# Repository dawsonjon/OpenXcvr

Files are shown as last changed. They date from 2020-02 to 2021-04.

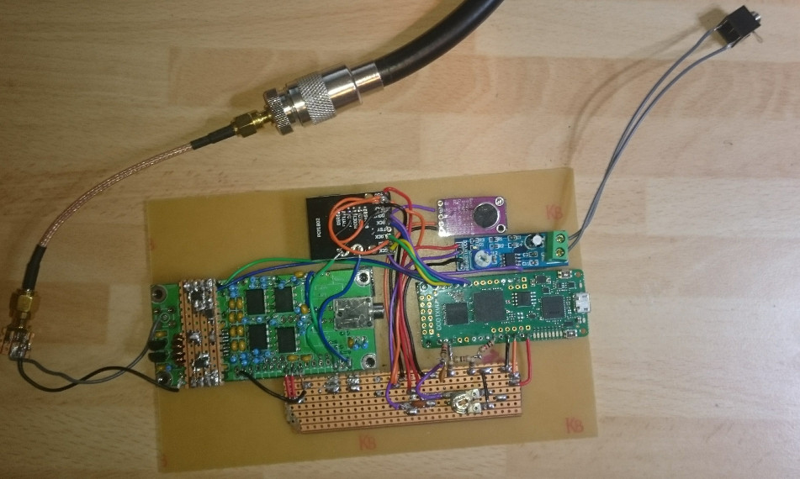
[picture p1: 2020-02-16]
images/prototype.jpg

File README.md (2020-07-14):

# Open XCVR

A cheap open-source Ham radio transceiver based on the [MAX1000 FPGA module](https://shop.trenz-electronic.de/en/Products/Trenz-Electronic/MAX1000-Intel-MAX10/). 

Features
+ High performance Intel MAX10 FPGA based DSP
+ SDR receiver 0.5-30MHz continuous
+ SDR transmitter 80m-10m ham bands
+ efficient 5W (ish) switched-mode PA for extended battery operation
+ Supports AM, FM, SSB and CW modes
+ audio output via 3.5mm headphone jack with integrated amplifier and provision for internal speaker
+ audio input via 3.5mm microphone jack with integrated pre-amplifier and provision for internal mic
+ support for straight and iambic telagraph keys with integrated electronic keyer
+ 500 general purpose memories
+ external 12v power via 2.5mm barrel jack provision for internal battery, integrated battery monitor
+ integrated Power/SWR meter
+ provision for GPS frequency calibration

The [wiki](https://github.com/dawsonjon/OpenXcvr/wiki) contains a detailed description of the hardware and firmware design

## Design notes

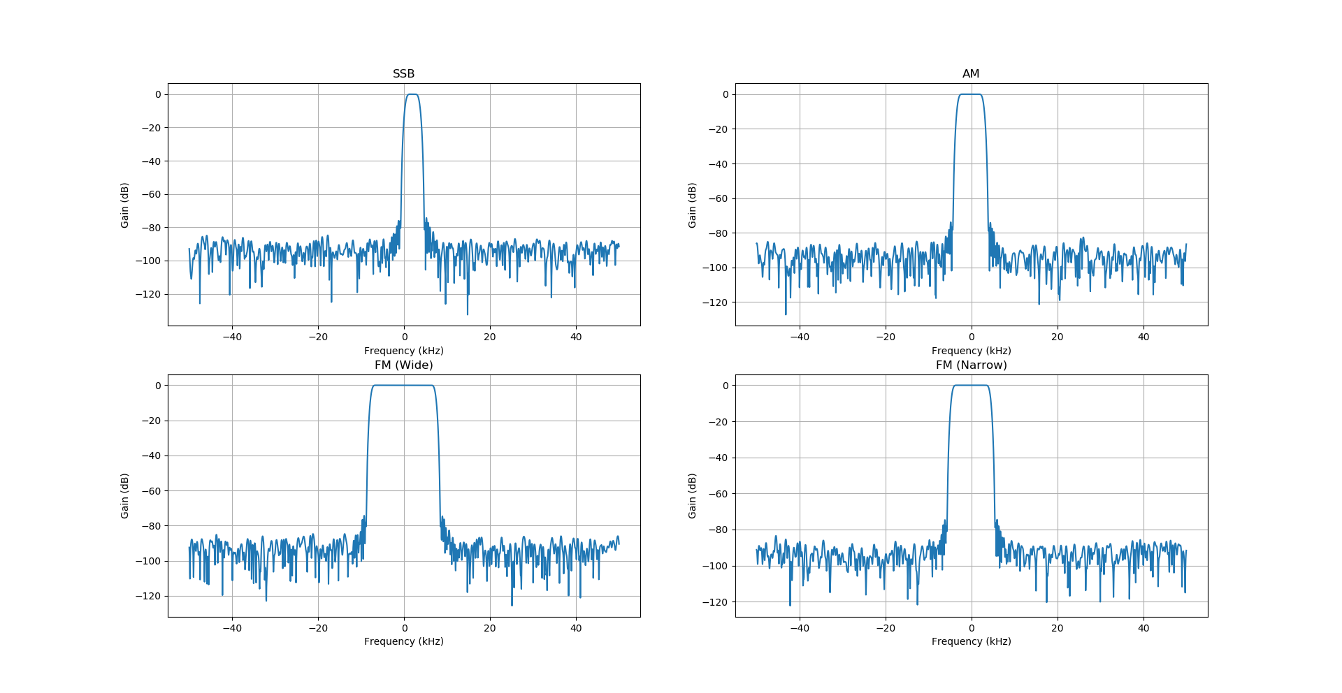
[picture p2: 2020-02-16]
images/digital_filter_response.png

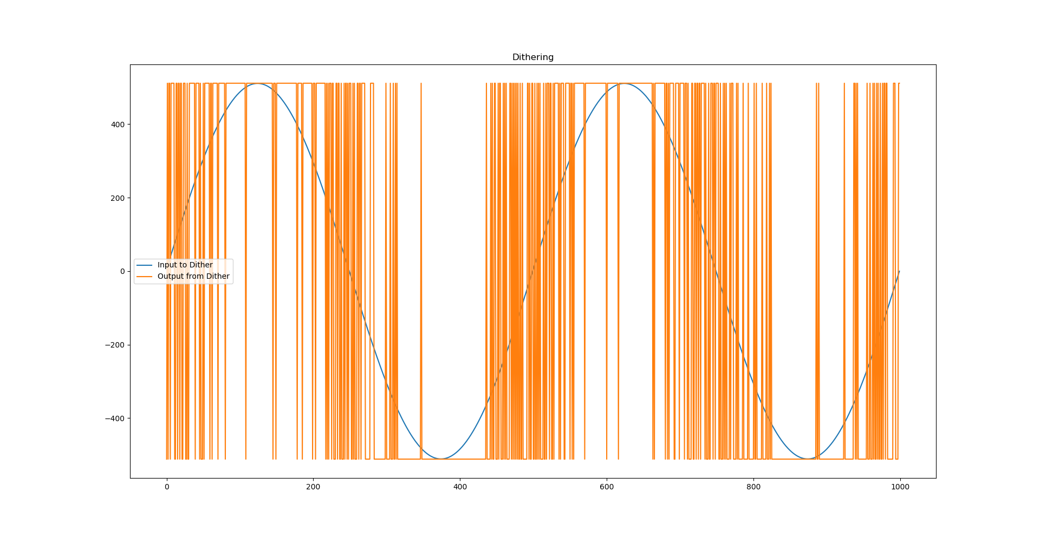
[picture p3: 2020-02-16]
images/dithering.png

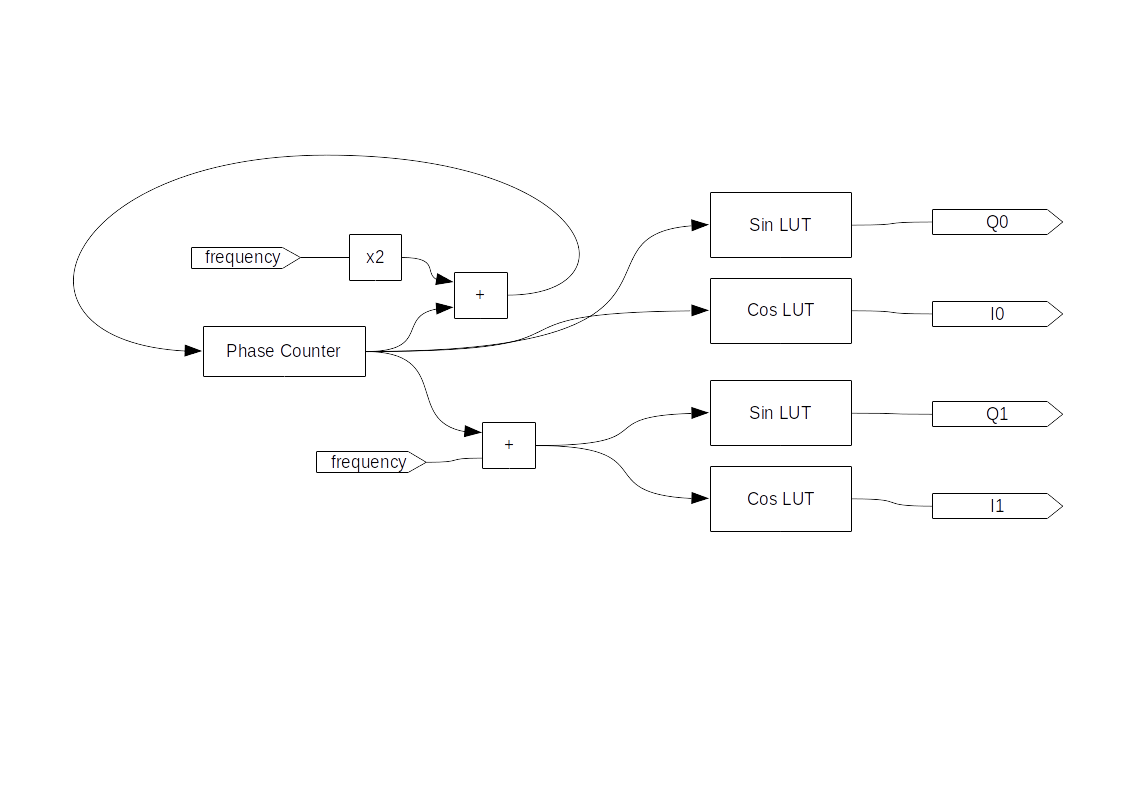
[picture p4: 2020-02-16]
images/NCO.png

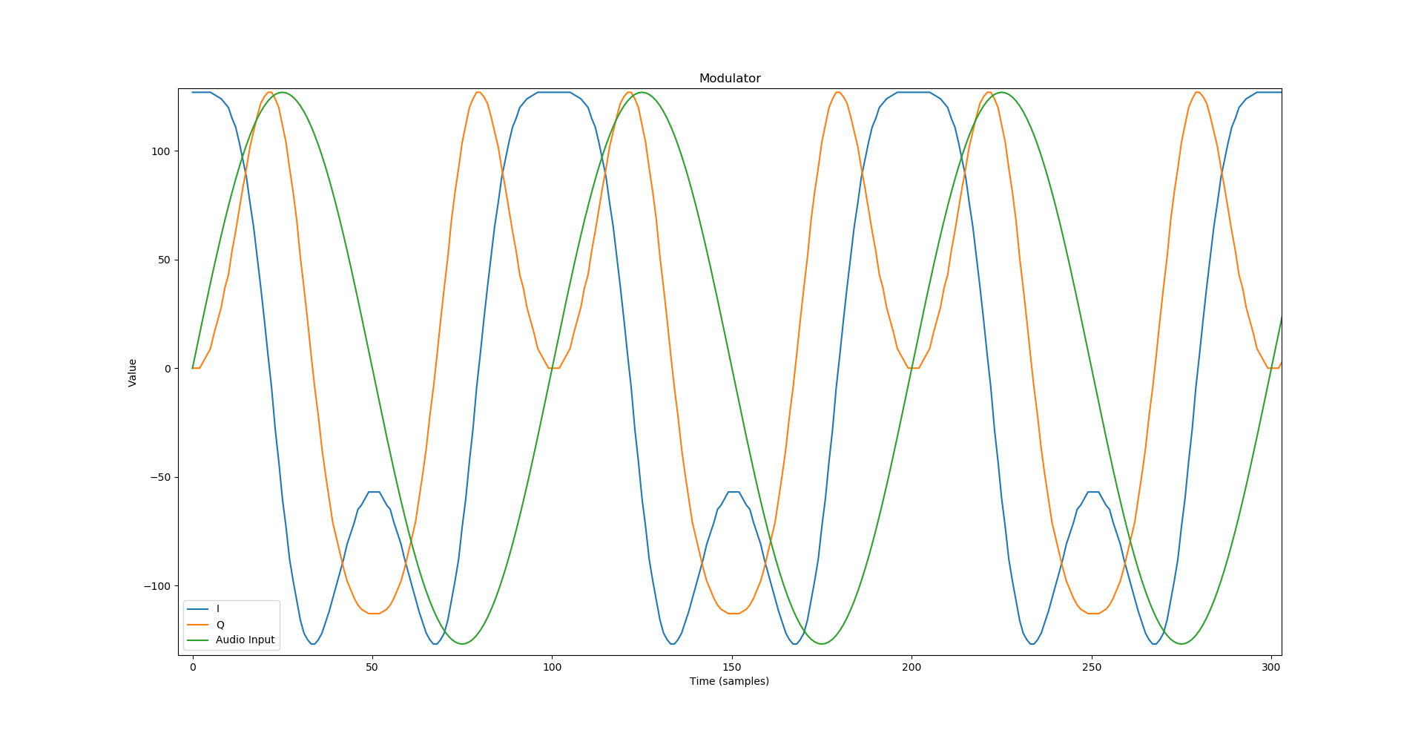
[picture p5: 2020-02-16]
images/modulator_fm.png

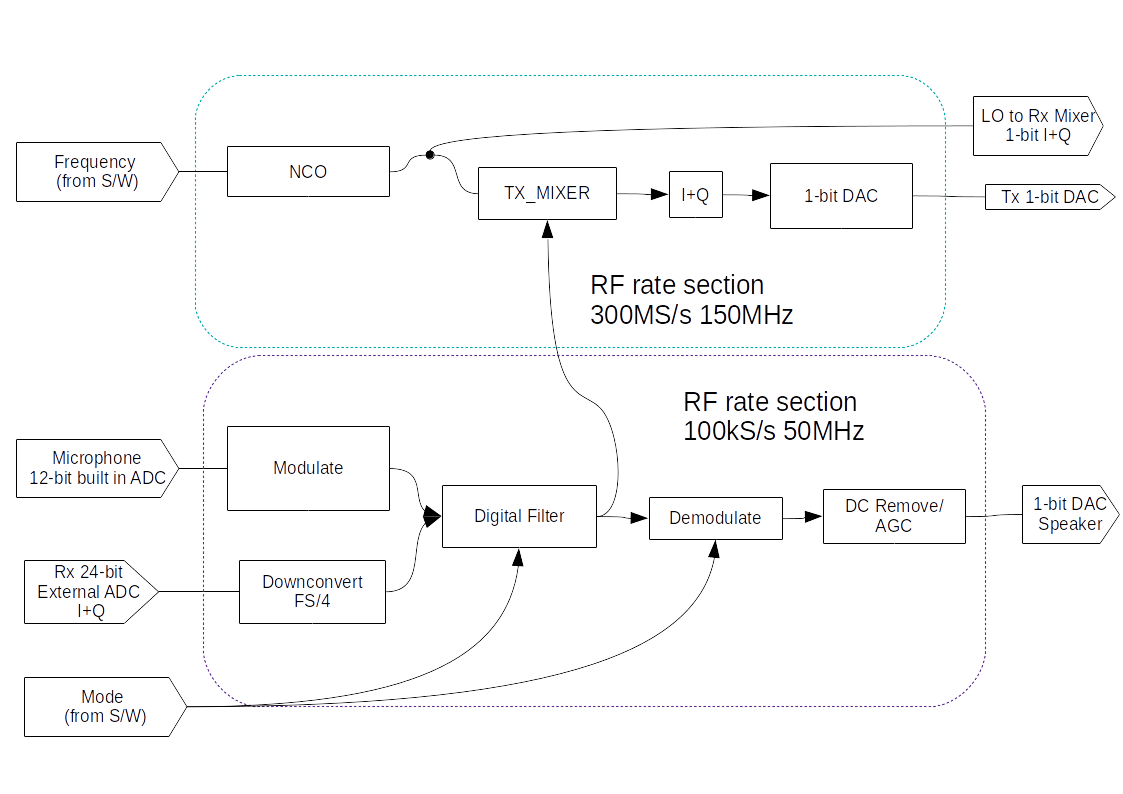
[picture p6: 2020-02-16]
images/firmware_top.png

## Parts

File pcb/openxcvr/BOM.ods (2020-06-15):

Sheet: Radio Board
Reference | Quantity | Value | Footprint | Datasheet | Total Cost GBP | Unit Cost GBP
C1 C2 C5 C6 | 4 | 10u | Capacitor_Tantalum_SMD:CP_EIA-3216-18_Kemet-A | ~ | 0.732 | 0.183 | https://uk.rs-online.com/web/p/tantalum-capacitors/5382278/
C21 C22 | 2 | 22n | Capacitor_SMD:C_0805_2012Metric | ~ | 0.258 | 0.129 | https://uk.rs-online.com/web/p/mlccs-multilayer-ceramic-capacitors/1795837/
C23 C24 C41 | 3 | 1n | Capacitor_SMD:C_0805_2012Metric | ~ | 0.3 | 0.1 | https://www.digikey.co.uk/product-detail/en/kemet/C0805C102J5GACTU/399-1136-1-ND/411411
C25 C26 | 2 | 1u | Capacitor_SMD:C_0805_2012Metric | ~ | 0.144 | 0.072 | https://uk.rs-online.com/web/p/mlccs-multilayer-ceramic-capacitors/1358614/
C3 C4 C7 C8 C10 C11 C12 C13 C14 C15 C17 C18 C19 C20 C51 C27 C28 C29 C30 C31 C32 C33 C46 C47 C48 C49 C16 | 27 | 100n | Capacitor_SMD:C_0805_2012Metric | ~ | 0.54 | 0.02 | https://uk.rs-online.com/web/p/mlccs-multilayer-ceramic-capacitors/1349144/
C34 C40 C42 | 3 | 390p | Capacitor_SMD:C_0805_2012Metric | ~ | 0.33 | 0.11 | https://www.digikey.co.uk/product-detail/en/kemet/C0805C391J5GACTU/399-1132-1-ND/411407
C35 C43 | 2 | 820p | Capacitor_SMD:C_0805_2012Metric | ~ | 0.032 | 0.016 | https://www.digikey.co.uk/product-detail/en/kemet/C0805C821J5GACTU/399-8119-1-ND/3471842
C36 C44 | 2 | 1n6 | Capacitor_SMD:C_0805_2012Metric | ~ | 0.84 | 0.42 | https://www.digikey.co.uk/product-detail/en/kemet/C0805C162J5GAC7800/399-15458-1-ND/7386856
C37 C45 | 2 | 3n | Capacitor_SMD:C_0805_2012Metric | ~ | 1.14 | 0.57 | https://www.digikey.co.uk/product-detail/en/kemet/C0805C302J5GAC7800/399-15039-1-ND/7382588
C38 | 1 | 100p | Capacitor_SMD:C_0805_2012Metric | ~ | 0.08 | 0.08 | https://www.digikey.co.uk/product-detail/en/kemet/C0805C101J5GACTU/399-1122-1-ND/411397
C39 | 1 | 200p | Capacitor_SMD:C_0805_2012Metric | ~ | 0.25 | 0.25 | https://www.digikey.co.uk/product-detail/en/kemet/C0805C201J5GAC7800/399-15466-1-ND/7386864
C50 | 1 | 47p | Capacitor_SMD:C_0805_2012Metric | ~ | 0.044 | 0.044 | https://uk.rs-online.com/web/p/mlccs-multilayer-ceramic-capacitors/2644270/
C9 | 1 | 47n | Capacitor_SMD:C_0805_2012Metric | ~ | 0.094 | 0.094 | https://uk.rs-online.com/web/p/mlccs-multilayer-ceramic-capacitors/0391303/
DS1 | 1 | WC1602A | Display:WC1602A | http://www.wincomlcd.com/pdf/WC1602A-SFYLYHTC06.pdf | 4.96 | 4.96 | https://www.rapidonline.com/winstar-wh1602b-yyh-jt-16x2-lcd-display-yellow-green-led-backlight-57-2226
FB1 FB2 FB3 | 3 | Ferrite_Bead | Inductor_SMD:L_0805_2012Metric | ~ | 0.516 | 0.172 | https://uk.rs-online.com/web/p/ferrite-beads/1241838/
H1 H2 H3 H4 | 4 | MountingHole_Pad | MountingHole:MountingHole_3.2mm_M3_Pad | ~ | 0 | 0 | N/A
J1 | 1 | Microphone | openxcvr:jack3.5mm switched | ~ | 0.662 | 0.662 | https://uk.rs-online.com/web/p/jack-plugs/9131021/
J2 | 1 | Mic | Connector_PinHeader_2.54mm:PinHeader_1x02_P2.54mm_Vertical | ~ | 0 | 0 | N/A
J3 | 1 | Speaker | Connector_PinHeader_2.54mm:PinHeader_1x02_P2.54mm_Vertical | ~ | 0 | 0 | N/A
J4 | 1 | Headphone | openxcvr:jack3.5mm switched | ~ | 0.662 | 0.662 | https://uk.rs-online.com/web/p/jack-plugs/9131021/
J5 | 1 | Conn_02x08_Odd_Even | Connector_PinHeader_2.54mm:PinHeader_2x08_P2.54mm_Vertical | ~ | 0 | 0 | N/A
J6 | 1 | GPS_CONNECTOR | Connector_PinHeader_2.54mm:PinHeader_1x02_P2.54mm_Vertical | ~ | 0 | 0 | N/A
J7 | 1 | KEY | openxcvr:jack3.5mm switched | ~ | 0.662 | 0.662 | https://uk.rs-online.com/web/p/jack-plugs/9131021/
J8 | 1 | Conn_01x03_Male | Connector_PinHeader_2.54mm:PinHeader_1x03_P2.54mm_Vertical | ~ | 0 | 0 | N/A
L1 L9 | 2 | 100n | Inductor_SMD:L_TDK_NLV32_3.2x2.5mm | ~ | 0.42 | 0.21 | https://www.digikey.co.uk/product-detail/en/tdk-corporation/NLV32T-R10J-EF/445-16614-1-ND/4766615
L10 L2 | 2 | 220n | Inductor_SMD:L_TDK_NLV32_3.2x2.5mm | ~ | 0.42 | 0.21 | https://www.digikey.co.uk/product-detail/en/tdk-corporation/NLV32T-R22J-EF/445-16622-1-ND/4766619
L11 L3 L5 | 3 | 470n | Inductor_SMD:L_TDK_NLV32_3.2x2.5mm | ~ | 0.63 | 0.21 | https://www.digikey.co.uk/product-detail/en/tdk-corporation/NLV32T-R47J-EF/445-16630-1-ND/4766623
L12 L4 L6 | 3 | 1u | Inductor_SMD:L_TDK_NLV32_3.2x2.5mm | ~ | 0.63 | 0.21 | https://www.digikey.co.uk/product-detail/en/tdk-corporation/NLV32T-1R0J-EF/445-16564-1-ND/4766590
L7 | 1 | 2u2 | Inductor_SMD:L_TDK_NLV32_3.2x2.5mm | ~ | 0.21 | 0.21 | https://www.digikey.co.uk/product-detail/en/tdk-corporation/NLV32T-2R2J-EF/445-16580-1-ND/4766598
L8 | 1 | 3u3 | Inductor_SMD:L_TDK_NLV32_3.2x2.5mm | ~ | 0.21 | 0.21 | https://www.digikey.co.uk/product-detail/en/tdk-corporation/NLV32T-3R3J-EF/445-16592-1-ND/4766604
R1 R2 R3 R8 | 4 | 1K | Resistor_SMD:R_0805_2012Metric | ~ | 0.156 | 0.039 | https://uk.rs-online.com/web/p/surface-mount-fixed-resistors/2230427/
R10 | 1 | 1M | Resistor_SMD:R_0805_2012Metric | ~ | 0.02 | 0.02 | https://uk.rs-online.com/web/p/surface-mount-fixed-resistors/2230821/
R11 R12 R6 R7 | 4 | 100K | Resistor_SMD:R_0805_2012Metric | ~ | 0.096 | 0.024 | https://uk.rs-online.com/web/p/surface-mount-fixed-resistors/2230691/
R13 R14 | 2 | 82 | Resistor_SMD:R_0805_2012Metric | ~ | 0.05 | 0.025 | https://uk.rs-online.com/web/p/surface-mount-fixed-resistors/7409057/
R15 R16 R21 R22 R23 R24 R25 R26 R27 R28 | 10 | 100 | Resistor_SMD:R_0805_2012Metric | ~ | 0.4 | 0.04 | https://uk.rs-online.com/web/p/surface-mount-fixed-resistors/0432214/
R17 R18 R34 R35 R36 R37 R38 R39 R41 | 9 | 2K2 | Resistor_SMD:R_0805_2012Metric | ~ | 0.261 | 0.029 | https://uk.rs-online.com/web/p/surface-mount-fixed-resistors/2230477/
R4 R5 R19 R20 R29 R30 R31 R32 R33 R40 R42 | 11 | 10K | Resistor_SMD:R_0805_2012Metric | ~ | 0.11 | 0.01 | https://uk.rs-online.com/web/p/surface-mount-fixed-resistors/1251189/
R43 R44 | 2 | 0 | Resistor_SMD:R_0805_2012Metric | ~ | 0.02 | 0.01 | https://uk.rs-online.com/web/p/surface-mount-fixed-resistors/1251187/
R9 | 1 | 47k | Resistor_SMD:R_0805_2012Metric | ~ | 0.013 | 0.013 | https://uk.rs-online.com/web/p/surface-mount-fixed-resistors/8075819/
RV3 | 1 | 10K | Potentiometer_THT:Potentiometer_Piher_PT-6-V_Vertical | ~ | 0.42 | 0.42 | https://uk.rs-online.com/web/p/trimmer-resistors/7432350/
SW1 SW2 SW3 SW4 | 4 | SW_Push | Button_Switch_THT:SW_PUSH_6mm | ~ | 1 | 0.25 | https://uk.rs-online.com/web/p/tactile-switches/3786476/
SW5 | 1 | Rotary_Encoder_Switch | Rotary_Encoder:RotaryEncoder_Alps_EC12E-Switch_Vertical_H20mm | ~ | 1.09 | 1.09 | https://uk.rs-online.com/web/p/mechanical-rotary-encoders/7295817/
T1 | 1 | BN43-2402 | openxcvr:bn43-2402-transformer | https://datasheet.octopart.com/CX2074NL-Pulse-datasheet-123678.pdf | 0.56 | 0.56 | http://www.amidoncorp.com/bn-43-2402/
U1 | 1 | PCM1802 | openxcvr:SSOP-20_5.3x7.2mm_P0.65mm |  | 1.84 | 1.84 | https://uk.rs-online.com/web/p/products/4619131/
U2 | 1 | TPA711D | Package_SO:SOIC-8_3.9x4.9mm_P1.27mm | https://www.ti.com/lit/ds/symlink/tpa711.pdf?ts=1590773198998 | 0.16 | 0.16 | https://uk.rs-online.com/web/p/products/6606310/
U3 | 1 | MCP6002-xSN | Package_SO:SOIC-8_3.9x4.9mm_P1.27mm | http://ww1.microchip.com/downloads/en/DeviceDoc/21733j.pdf | 0.25 | 0.25 | https://uk.rs-online.com/web/p/op-amps/6283598/
U4 | 1 | LM4562 | Package_SO:SOIC-8_3.9x4.9mm_P1.27mm | http://www.ti.com/lit/ds/symlink/lm4562.pdf | 1.29 | 1.29 | https://uk.farnell.com/texas-instruments/lm4562ma-nopb/op-amp-audio-dual-hf-8-so-powerwise/dp/3004532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
U5 | 1 | FST3253 | Package_SO:SOIC-16_3.9x9.9mm_P1.27mm | http://www.ti.com/lit/gpn/sn74cbt3253 | 0.166 | 0.166 | https://uk.rs-online.com/web/p/products/8076086/
U6 U7 | 2 | 74CBT3251 | Package_SO:SOIC-16_3.9x9.9mm_P1.27mm | http://www.ti.com/lit/gpn/sn74LS251 | 1.18 | 0.59 | https://www.digikey.co.uk/product-detail/en/SN74CBT3251DR/296-49883-1-ND/9462753?so=64190438
U8 | 1 | MAX_1000 | openxcvr:max1000 |  | 18.68 | 18.68 | https://shop.trenz-electronic.de/en/TEI0001-03-08-C8-MAX1000-IoT-Maker-Board-8KLE-8-MByte-RAM
U9 | 1 | 24LC256 | Package_SO:SOIC-8_3.9x4.9mm_P1.27mm | http://ww1.microchip.com/downloads/en/devicedoc/21203m.pdf | 0.622 | 0.622 | https://uk.rs-online.com/web/p/eeprom/0454331/
 |  |  |  |  | 43.15

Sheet: Transmit Board
Reference | Quantity | Value | Footprint | Total Price GBP | Unit Price GBP
C1 C13 | 2 | 56p | Capacitor_SMD:C_0805_2012Metric | 0.74 | 0.37 | https://www.digikey.co.uk/product-detail/en/08052U560GAT2A/478-10479-1-ND/6797386?so=64190438
C10 C6 | 2 | 390p | Capacitor_SMD:C_0805_2012Metric | 0.22 | 0.11 | https://www.digikey.co.uk/product-detail/en/kemet/C0805C391J5GACTU/399-1132-1-ND/411407
C11 C7 | 2 | 680p | Capacitor_SMD:C_0805_2012Metric | 0.66 | 0.33 | https://www.digikey.co.uk/product-detail/en/C0805C621J2GAC7800/399-17640-1-ND/8572640?so=64190438
C12 C8 | 2 | 1.2n | Capacitor_SMD:C_0805_2012Metric | 0.52 | 0.26 | https://www.digikey.co.uk/product-detail/en/C0805C122J2GAC7800/399-17620-1-ND/8572620?so=64190438
C14 C2 | 2 | 180p | Capacitor_SMD:C_0805_2012Metric | 0.54 | 0.27 | https://www.digikey.co.uk/product-detail/en/08052A181JAT2A/478-10441-1-ND/6797354?so=64190438
C15 C3 | 2 | 270p | Capacitor_SMD:C_0805_2012Metric | 0.56 | 0.28 | https://www.digikey.co.uk/product-detail/en/GRM21A5C2D271JW01D/490-16817-1-ND/7595725?so=64190438
C16 C4 | 2 | 470p | Capacitor_SMD:C_0805_2012Metric | 0.54 | 0.27 | https://www.digikey.co.uk/product-detail/en/08052A471JAT2A/478-1276-1-ND/564308?so=64190438
C18 C19 | 2 | 10u | Capacitor_Tantalum_SMD:CP_EIA-3216-18_Kemet-A | 0.366 | 0.183 | https://uk.rs-online.com/web/p/tantalum-capacitors/5382278/
C21 C26 | 2 | 68n | Capacitor_SMD:C_0805_2012Metric | 0.044 | 0.022 | https://uk.rs-online.com/web/p/mlccs-multilayer-ceramic-capacitors/0147796/
C22 C23 C24 C27 C28 C17 C20 | 7 | 100n | Capacitor_SMD:C_0805_2012Metric | 0.56 | 0.08 | https://www.digikey.co.uk/product-detail/en/CL21B104KCFNNNE/1276-6840-1-ND/5961699?so=64190438
C25 | 1 | 220n | Capacitor_SMD:C_0805_2012Metric | 0.026 | 0.026 | https://uk.rs-online.com/web/p/mlccs-multilayer-ceramic-capacitors/0390996/
C5 C9 | 2 | 150p | Capacitor_SMD:C_0805_2012Metric | 0.54 | 0.27 | https://www.digikey.co.uk/product-detail/en/08052A151JAT2A/478-1273-1-ND/564305?so=64190438
D1 D2 D3 D4 | 4 | 1N4148W | Diode_SMD:D_SOD-123 | 0.276 | 0.069 | https://uk.rs-online.com/web/p/switching-diodes/7003671/
D5 D6 | 2 | 1N5711 | Diode_THT:D_DO-35_SOD27_P7.62mm_Horizontal | 0.64 | 0.32 | https://www.digikey.co.uk/product-detail/en/stmicroelectronics/1N5711/497-2499-1-ND/603881
D7 | 1 | D_Schottky | openxcvr:D_SOD-106 | 0.162 | 0.162 | https://uk.rs-online.com/web/p/products/7002665/
D8 | 1 | 51v | Diode_SMD:D_SOD-123 | 0.042 | 0.042 | https://uk.rs-online.com/web/p/products/7930933/
H1 H2 H3 H4 | 4 | MountingHole_Pad | MountingHole:MountingHole_3.2mm_M3_Pad | 0 | 0
J1 | 1 | Conn_Coaxial | Connector_Coaxial:BNC_Amphenol_B6252HB-NPP3G-50_Horizontal | 1.26 | 1.26 | https://uk.rs-online.com/web/p/coaxial-connectors/5121247/?searchHistory=%7B%22enabled%22%3Atrue%7D
J2 | 1 | RADIO BOARD CONNECTOR | Connector_PinHeader_2.54mm:PinHeader_2x08_P2.54mm_Vertical | 0 | 0
J3 | 1 | Power Jack | Connector_BarrelJack:BarrelJack_Horizontal | 1.07 | 1.07 | https://uk.rs-online.com/web/p/dc-power-connectors/8840944/?searchHistory=%7B%22enabled%22%3Atrue%7D
J4 | 1 | Battery Connector | Connector_PinHeader_2.54mm:PinHeader_1x02_P2.54mm_Vertical | 0 | 0
K1 K2 K3 K4 | 4 | G5V-2 | Relay_THT:Relay_DPDT_Omron_G5V-2 | 8.32 | 2.08 | https://uk.rs-online.com/web/p/non-latching-relays/1966276/
L1 L9 | 2 | 303n | openxcvr:FT37-INDUCTOR | 0.88 | 0.44 | https://www.amidoncorp.com/t37-6/
L10 L2 | 2 | 773n | openxcvr:FT37-INDUCTOR | 0.88 | 0.44 | https://www.amidoncorp.com/t37-6/
L11 L3 | 2 | 1.380u | openxcvr:FT37-INDUCTOR | 0.88 | 0.44 | https://www.amidoncorp.com/t37-6/
L12 L4 | 2 | 2.434u | openxcvr:FT37-INDUCTOR | 0.88 | 0.44 | https://www.amidoncorp.com/t37-2/
L13 L14 | 2 | 100u | openxcvr:L_SMT_INDUCTOR | 0.68 | 0.34 | https://uk.rs-online.com/web/p/wire-wound-surface-mount-inductors/7418997/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
L15 | 1 | L | openxcvr:FT50-43 INDUCTOR | 0.6 | 0.6 | http://www.amidoncorp.com/ft-50-43/
L5 | 1 | 382n | openxcvr:FT37-INDUCTOR | 0.44 | 0.44 | https://www.amidoncorp.com/t37-6/
L6 | 1 | 904n | openxcvr:FT37-INDUCTOR | 0.44 | 0.44 | https://www.amidoncorp.com/t37-6/
L7 | 1 | 1.698u | openxcvr:FT37-INDUCTOR | 0.44 | 0.44 | https://www.amidoncorp.com/t37-6/
L8 | 1 | 3.012u | openxcvr:FT37-INDUCTOR | 0.44 | 0.44 | https://www.amidoncorp.com/t37-2/
Q1 Q2 Q4 Q5 Q6 Q3 | 6 | BS170 | Package_TO_SOT_THT:TO-92_Inline | 1.182 | 0.197 | https://export.rsdelivers.com/product/on-semiconductor/bs170-d27z/on-semiconductor-bs170-d27z-digital-transistor-3/1868777
R1 R2 R3 | 3 | 10K | Resistor_SMD:R_0805_2012Metric | 0.03 | 0.01 | https://uk.rs-online.com/web/p/surface-mount-fixed-resistors/1251189/
R10 R11 R6 R9 | 4 | 100 | Resistor_SMD:R_0805_2012Metric | 0.16 | 0.04 | https://uk.rs-online.com/web/p/surface-mount-fixed-resistors/0432214/
R14 R15 | 2 | 10 | Resistor_SMD:R_0805_2012Metric | 0.02 | 0.01 | https://uk.rs-online.com/web/p/surface-mount-fixed-resistors/8123372/
R16 R17 R18 | 3 | 4k7 | Resistor_SMD:R_0805_2012Metric | 0.012 | 0.004 | https://uk.rs-online.com/web/p/surface-mount-fixed-resistors/0432416/
R19 R21 R12 R13 R4 R5 R7 | 7 | 10k | Resistor_SMD:R_0805_2012Metric | 0.07 | 0.01 | https://uk.rs-online.com/web/p/surface-mount-fixed-resistors/1251189/
R8 | 1 | 1K | Resistor_SMD:R_0805_2012Metric | 0.039 | 0.039 | https://uk.rs-online.com/web/p/surface-mount-fixed-resistors/2230427/
RV1 | 1 | 10k | Potentiometer_THT:Potentiometer_Piher_PT-6-V_Vertical | 0.42 | 0.42 | https://uk.rs-online.com/web/p/trimmer-resistors/7432350/
SW1 | 1 | POWER SWITCH | openxcvr:RS PCB Toggle Switch | 1.56 | 1.56 | https://uk.rs-online.com/web/p/products/7346971/
TR1 TR2 | 2 | FT50-43Transformer | openxcvr:FT50-43 Transformer | 1.2 | 0.6 | http://www.amidoncorp.com/ft-50-43/
U1 | 1 | LM7805CV_TO220 | Package_TO_SOT_THT:TO-220-3_Vertical | 0.42 | 0.42 | https://uk.rs-online.com/web/p/linear-voltage-regulators/7931346/?searchHistory=%7B%22enabled%22%3Atrue%7D
U2 U3 | 2 | to220heatsink | openxcvr:to220 heatsink | 0.312 | 0.156 | https://uk.rs-online.com/web/p/heatsinks/7124257/?searchHistory=%7B%22enabled%22%3Atrue%7D
U4 | 1 | MCP1406 | Package_SO:SOIC-8_3.9x4.9mm_P1.27mm | 0.668 | 0.668 | https://uk.rs-online.com/web/p/products/0403610/
U5 | 1 | DMC3056LSS | Package_SO:SOP-8_3.9x4.9mm_P1.27mm | 0.076 | 0.076 | https://uk.rs-online.com/web/p/products/8234037/
U6 | 1 | 74AC00 | Package_SO:SOIC-14_3.9x8.7mm_P1.27mm | 0.466 | 0.466 | https://uk.rs-online.com/web/p/logic-gates/7390145/?searchHistory=%7B%22enabled%22%3Atrue%7D
 |  |  |  | 30.281

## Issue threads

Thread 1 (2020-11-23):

Query on project progress

bob-g4bby, 2020-11-23:
Hi Jon,
Not an issue - wondered how you were getting on with using the transceiver on-air, whether you use it portable yet and have you got the pcbs working yet. I've been messing around with sdrs for as long as they've been round - see my QRZ page.
Best regards, Bob G4BBY

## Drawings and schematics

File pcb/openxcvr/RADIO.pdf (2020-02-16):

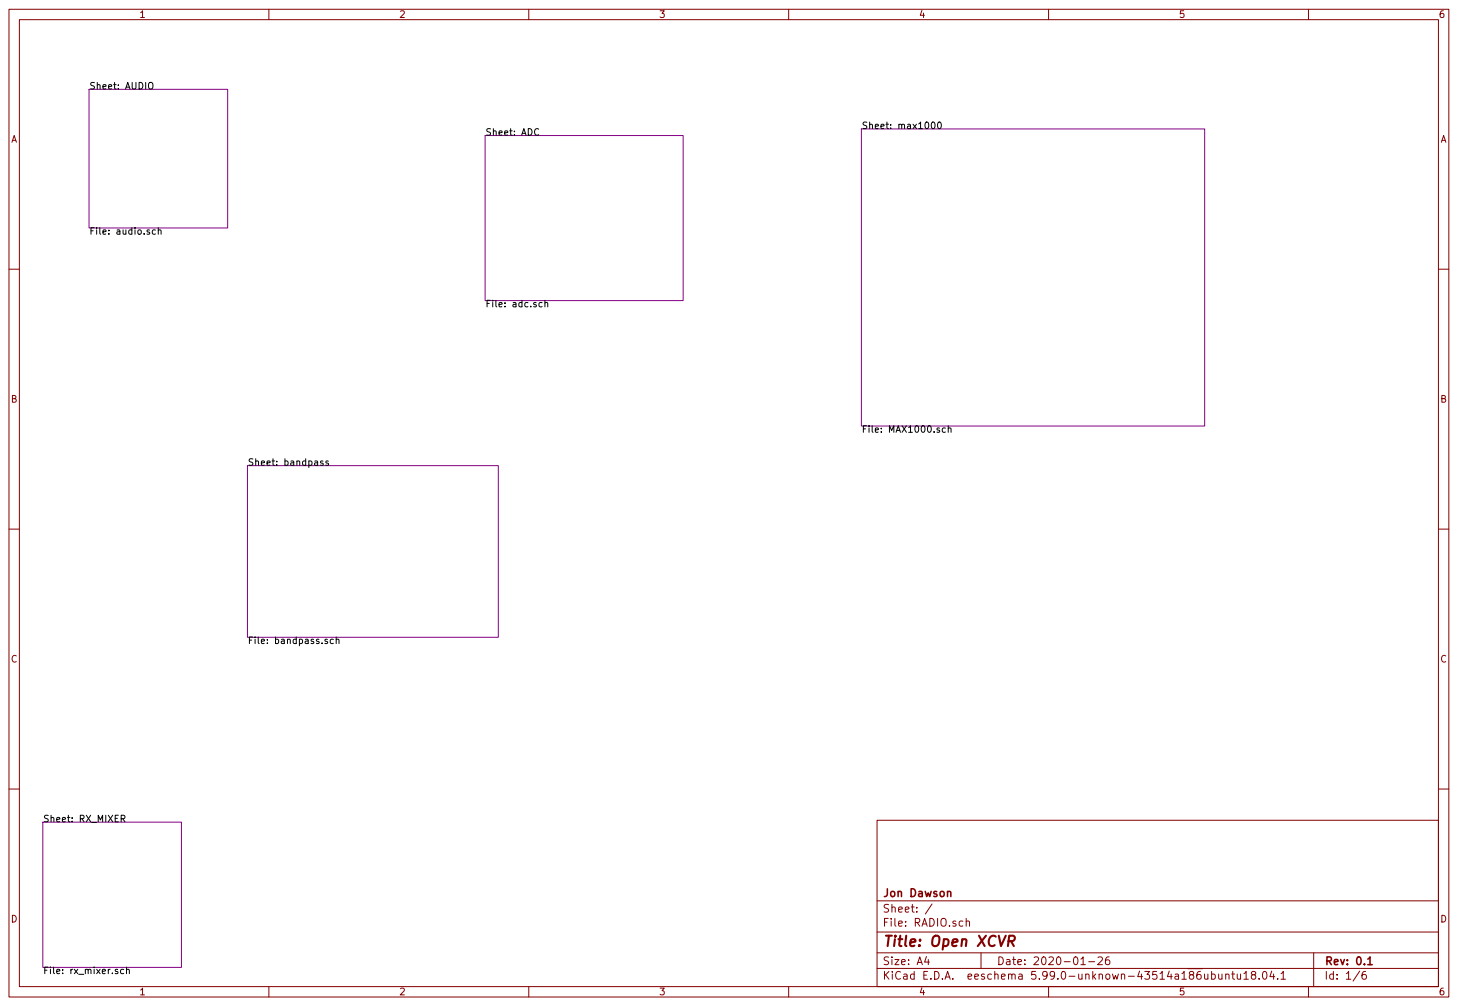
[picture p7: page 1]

File: adc.sch Sheet: AUDIO
File: audio.sch Sheet: RX_MIXER

File: RADIO.sch Sheet: / Jon Dawson

Id: 1/6 Title: Open XCVR

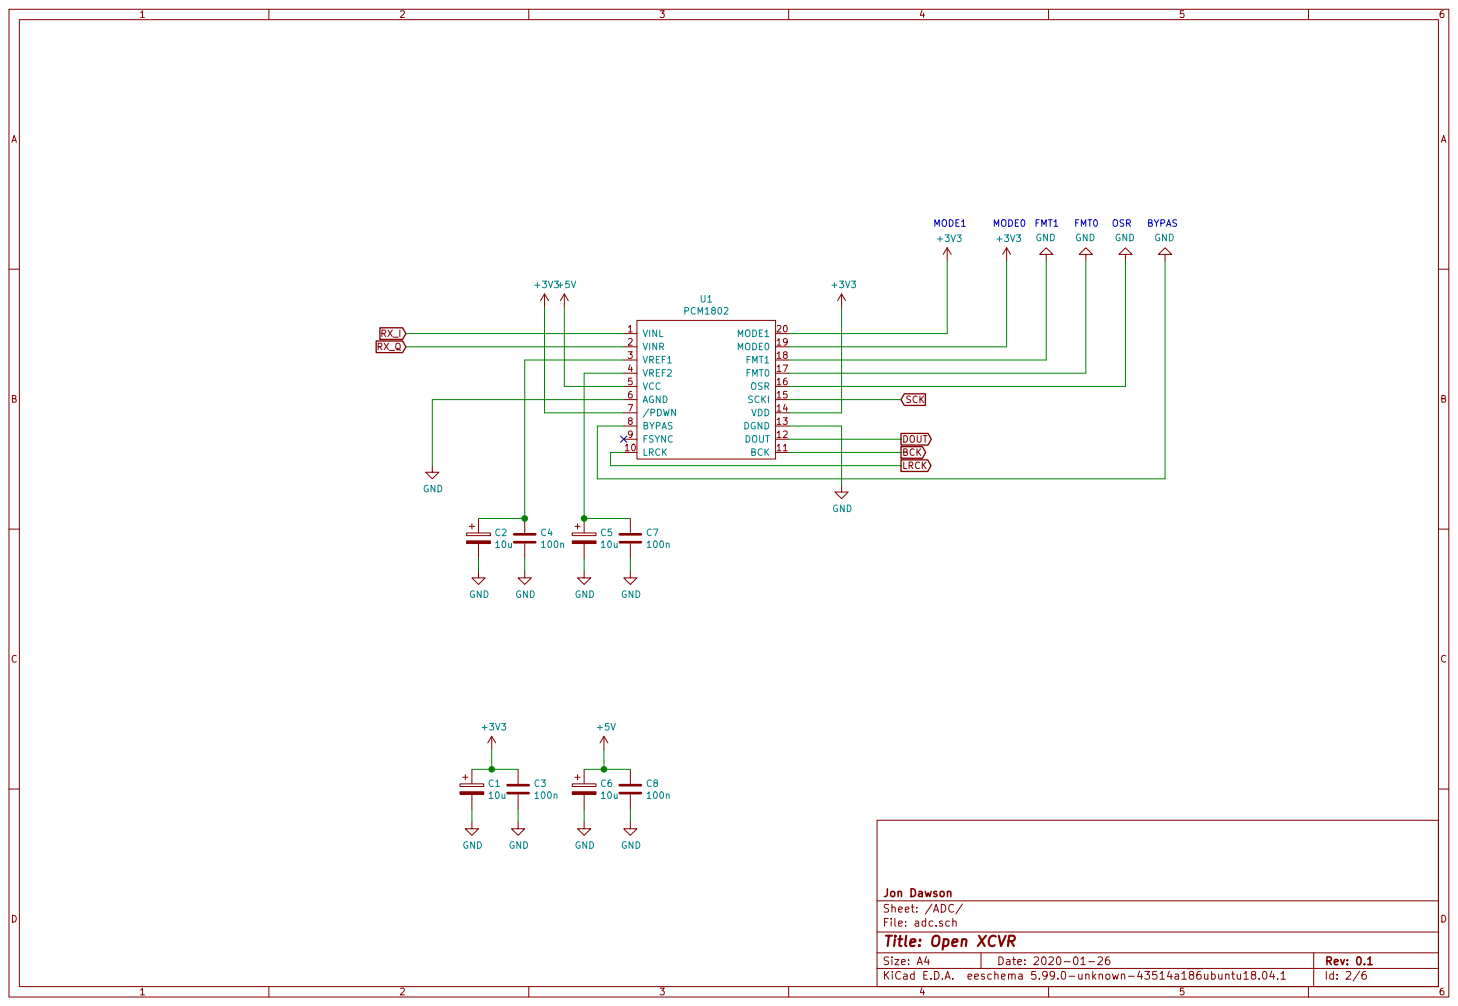
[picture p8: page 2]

File: adc.sch Sheet: /ADC/ Jon Dawson GND

Id: 2/6 Title: Open XCVR

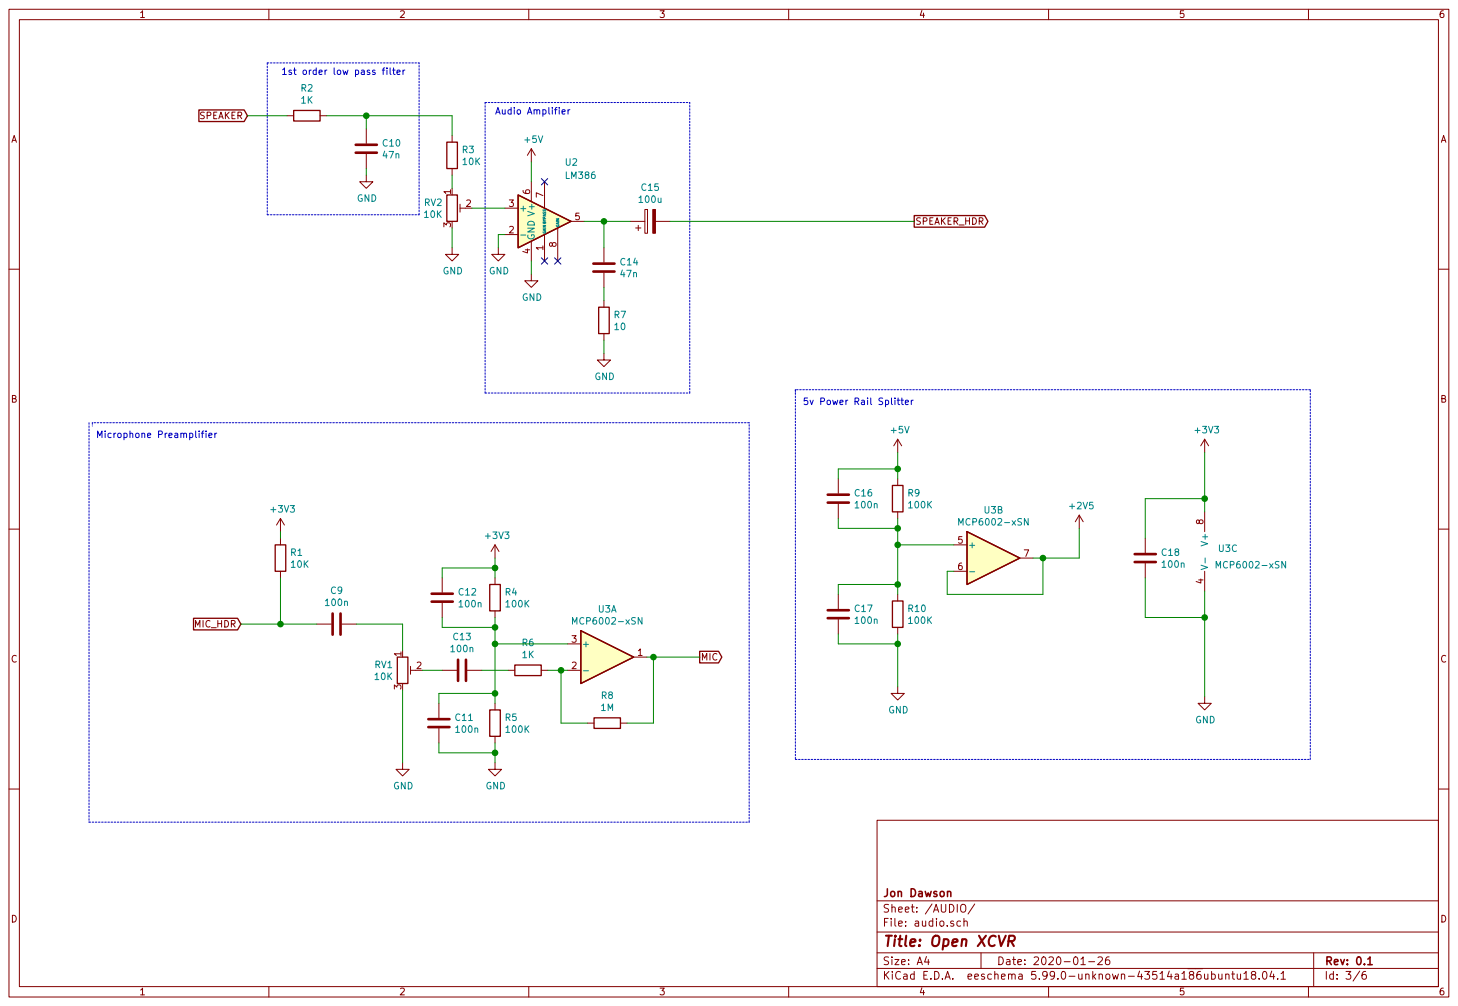
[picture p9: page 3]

File: audio.sch Sheet: /AUDIO/ Jon Dawson

Id: 3/6 Title: Open XCVR

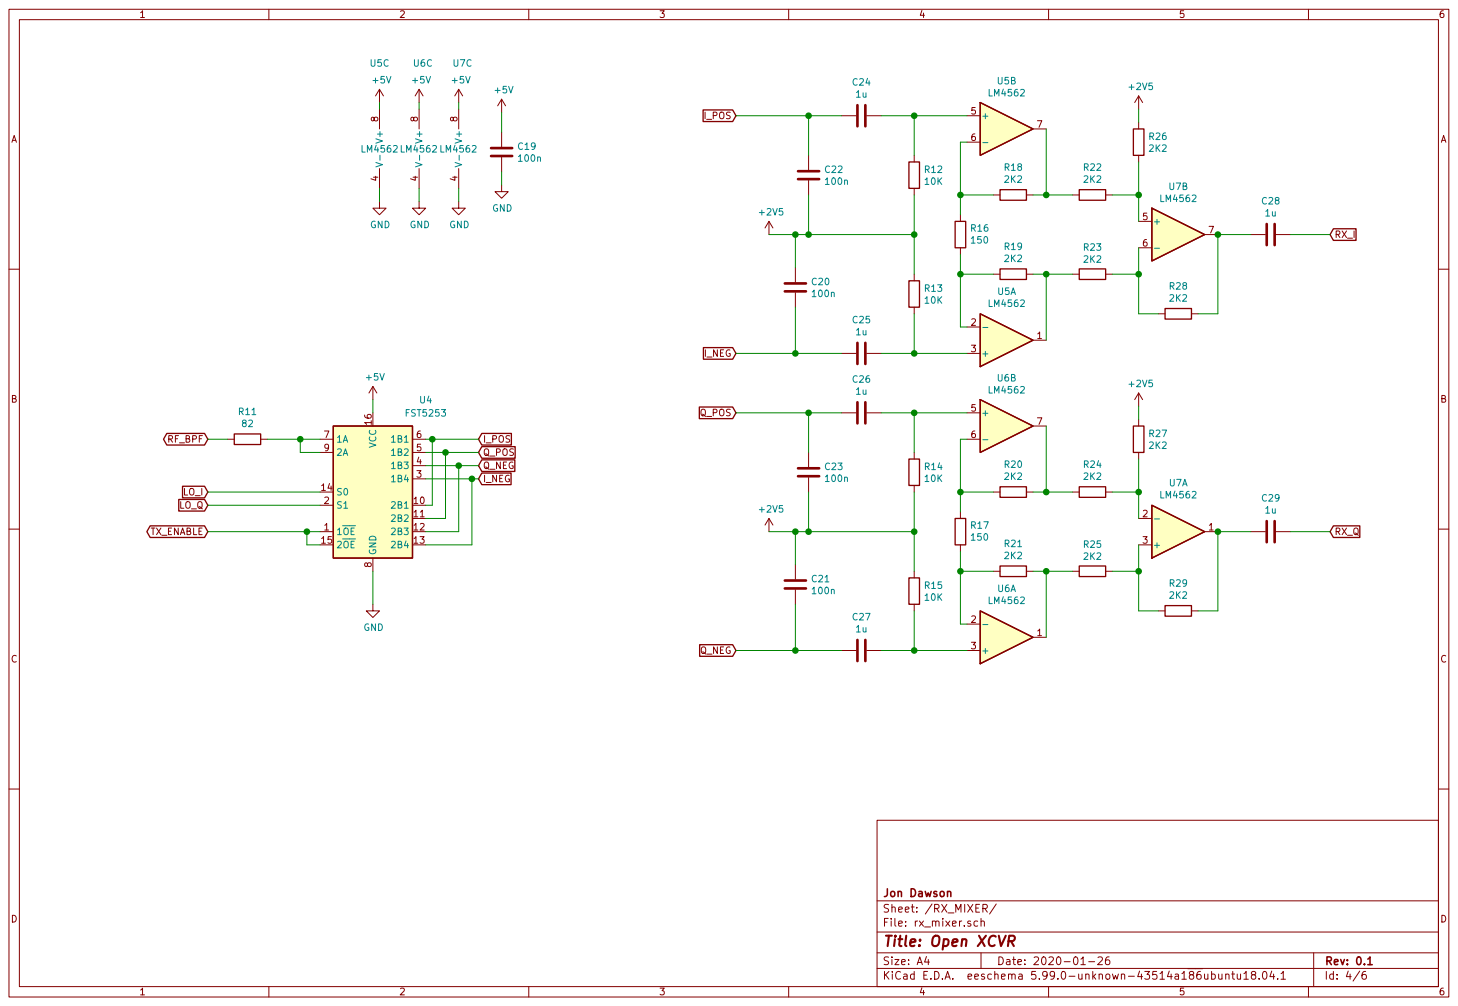
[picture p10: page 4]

File: rx_mixer.sch
Id: 4/6 Title: Open XCVR

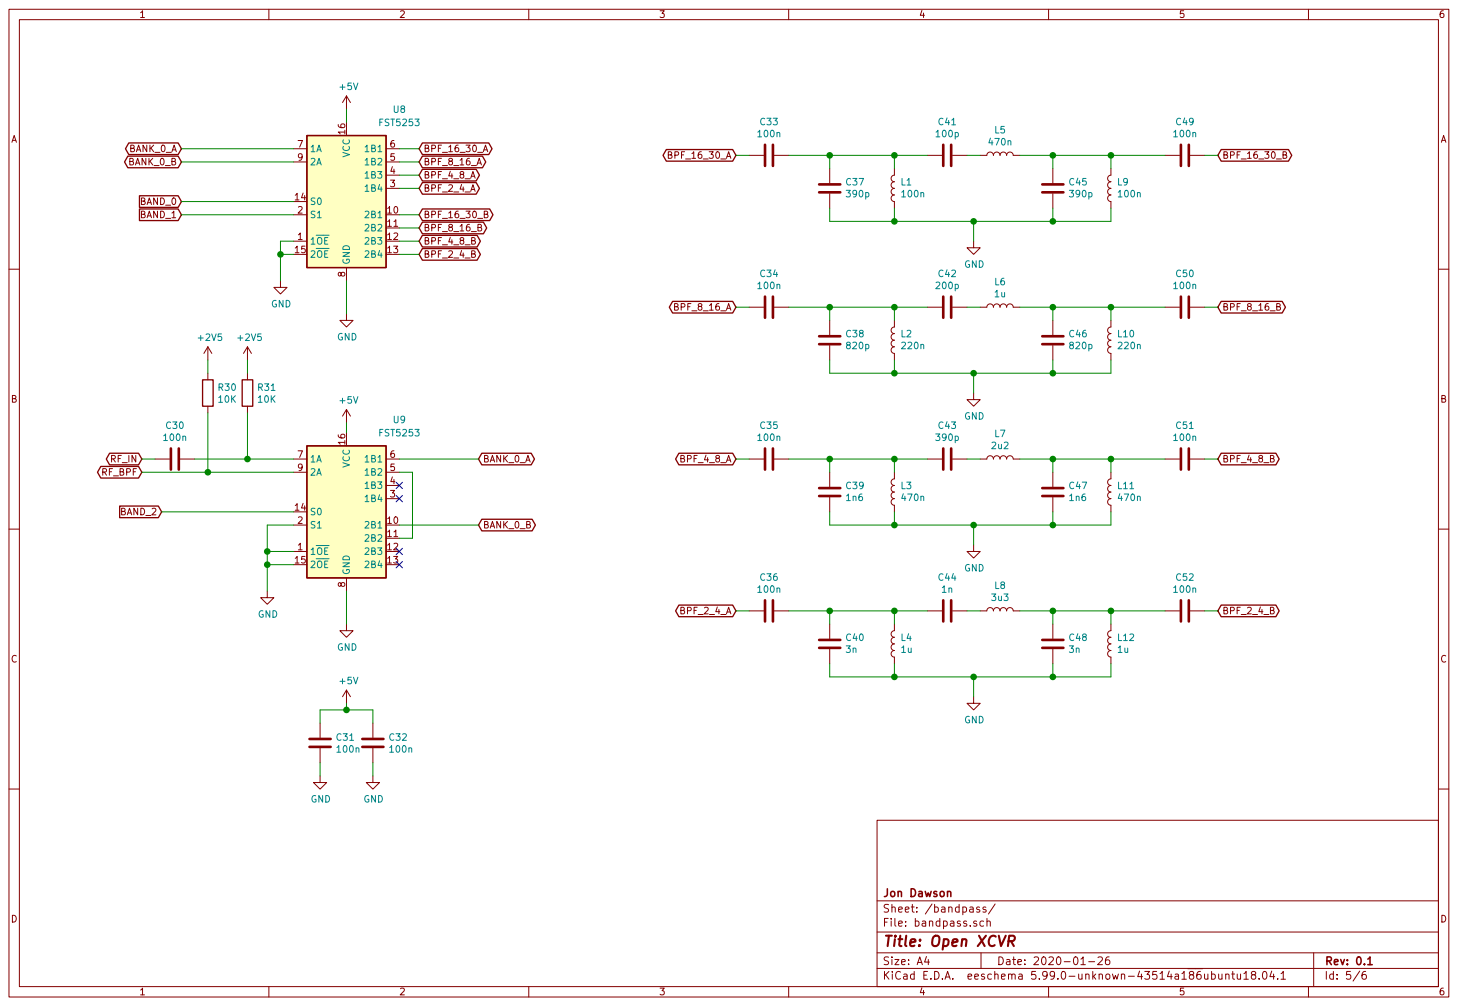
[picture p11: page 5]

Sheet: /bandpass/ Jon Dawson

File: bandpass.sch
Id: 5/6 Title: Open XCVR

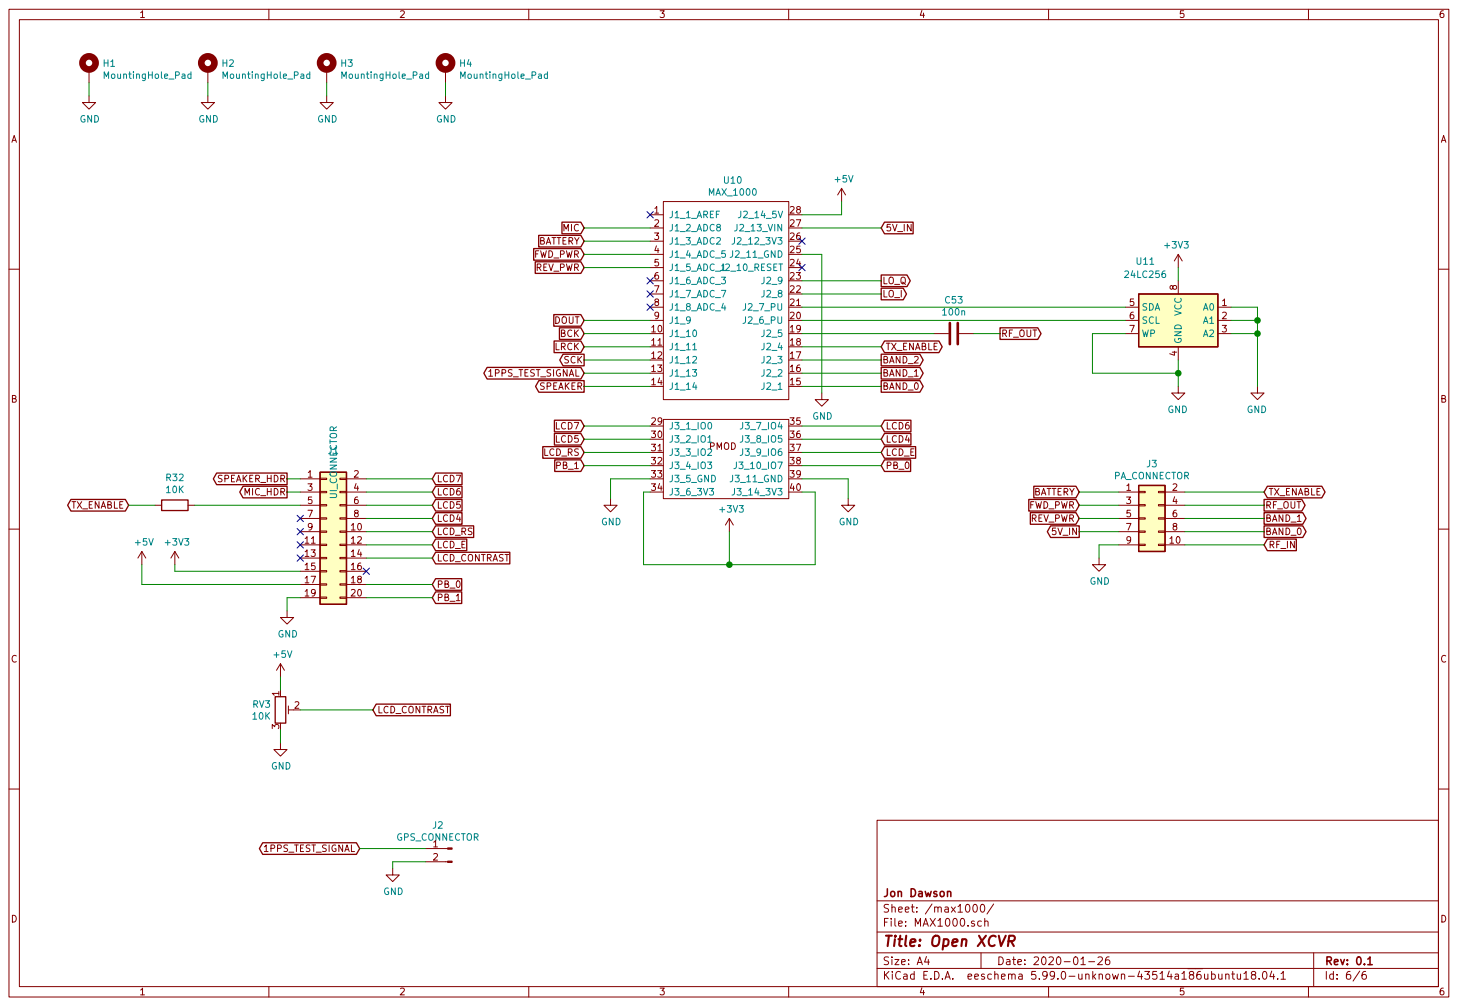
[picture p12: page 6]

4 SDA 5 SCL 6 WP 7 VCC

Id: 6/6 Title: Open XCVR

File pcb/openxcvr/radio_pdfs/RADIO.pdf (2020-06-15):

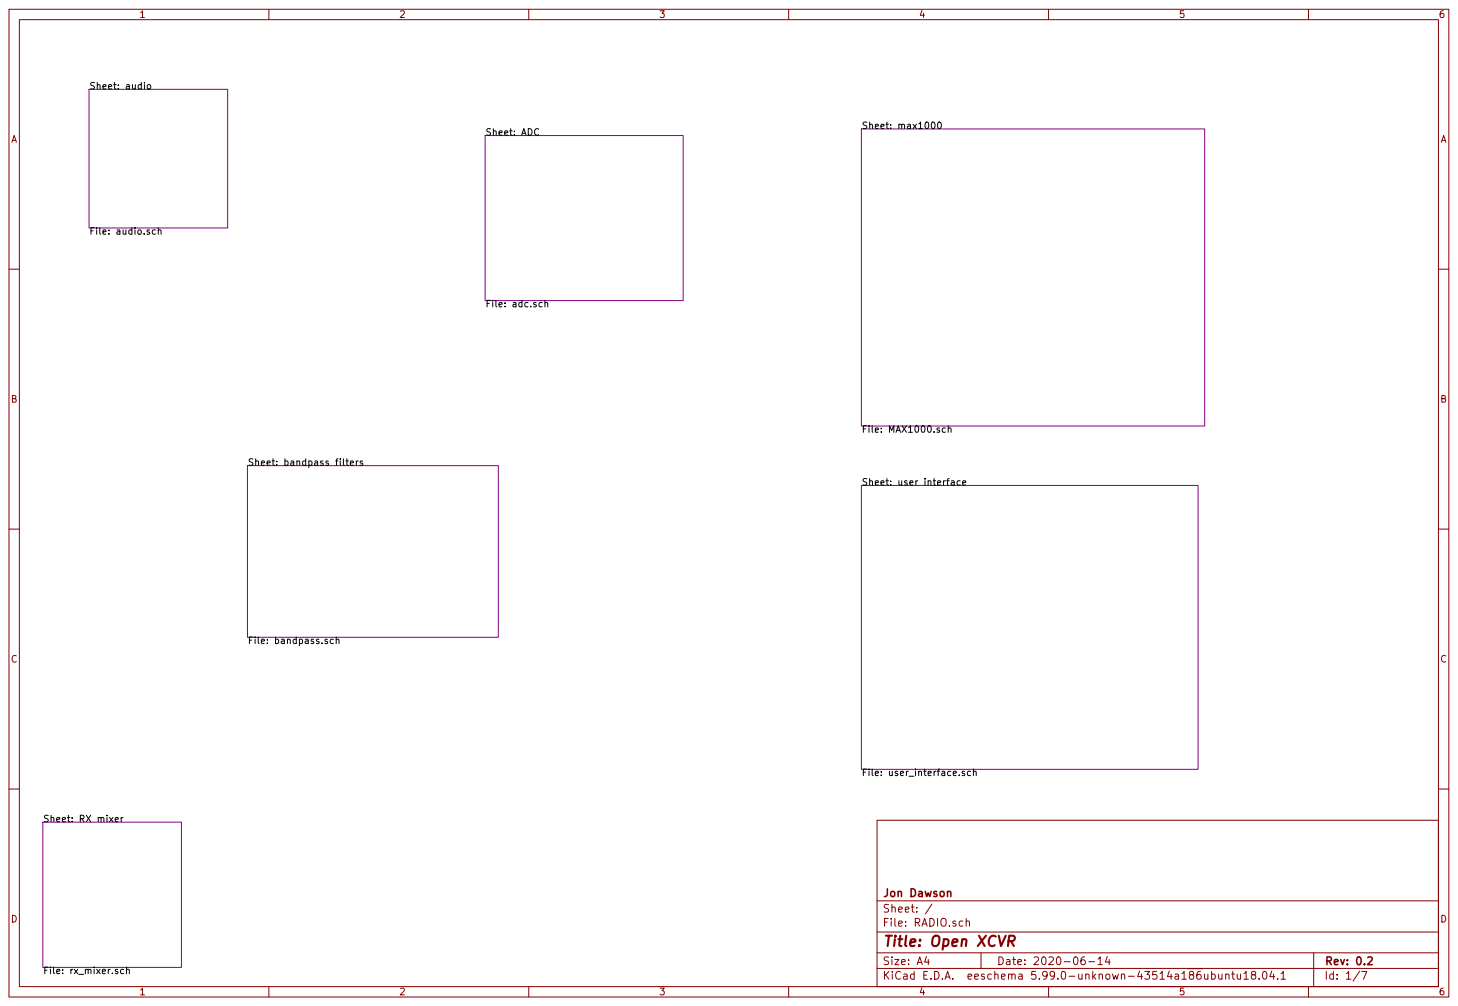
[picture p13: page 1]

Sheet: max1000 File: MAX1000.sch Sheet: user interface File: user_interface.sch

File: adc.sch Sheet: RX mixer File: rx_mixer.sch

File: RADIO.sch Sheet: / Jon Dawson

Id: 1/7 Title: Open XCVR

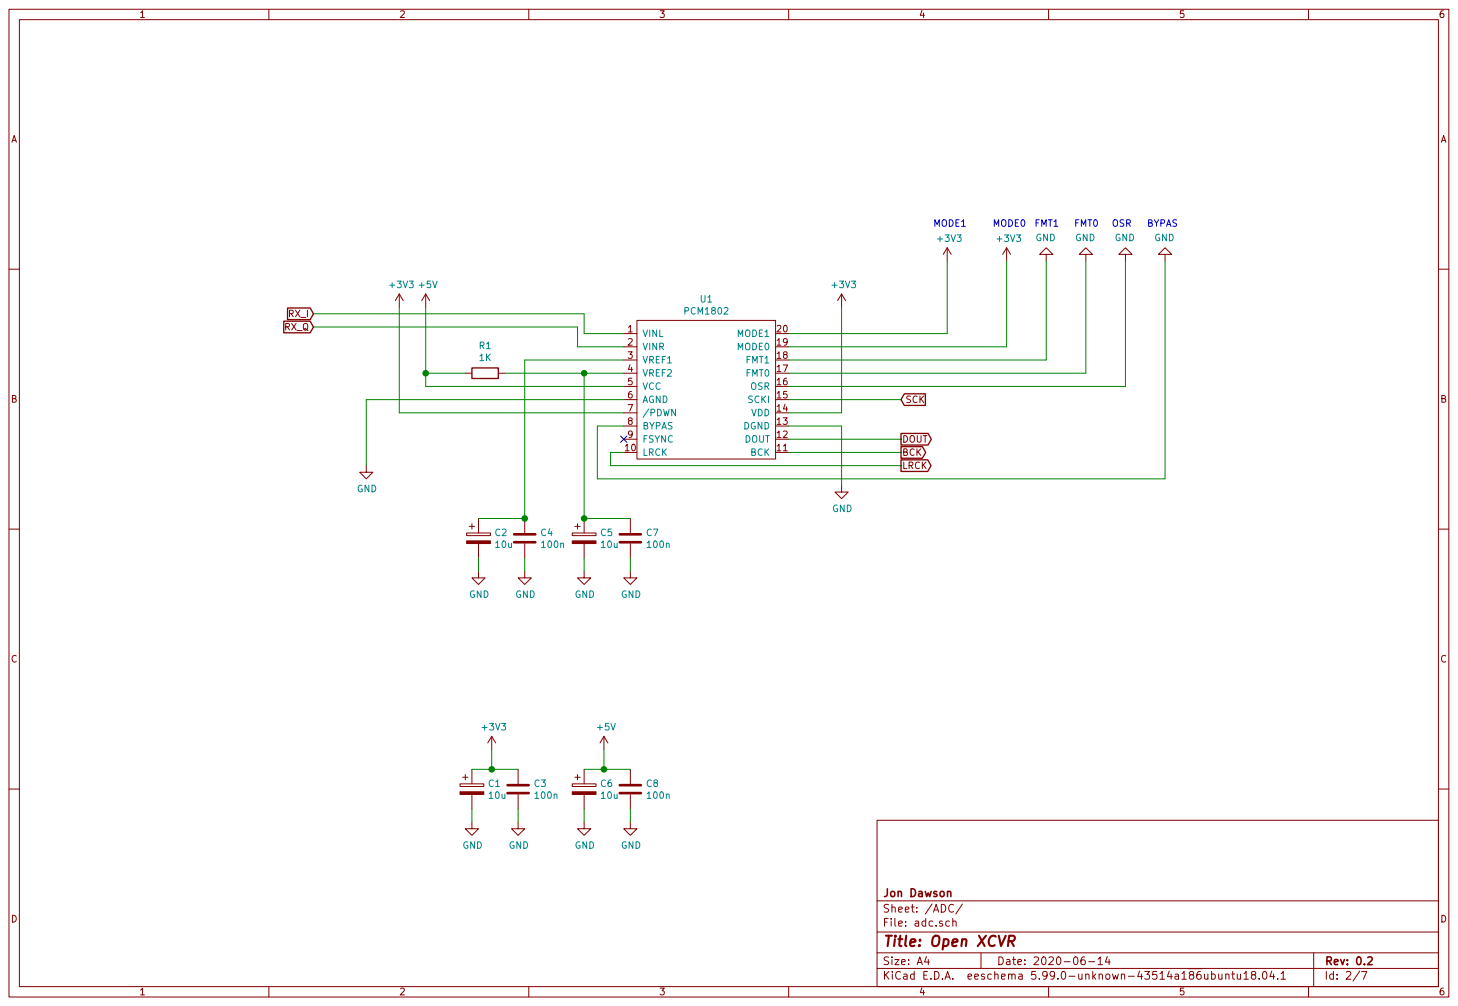
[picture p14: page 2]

File: adc.sch Sheet: /ADC/ Jon Dawson

Id: 2/7 Title: Open XCVR

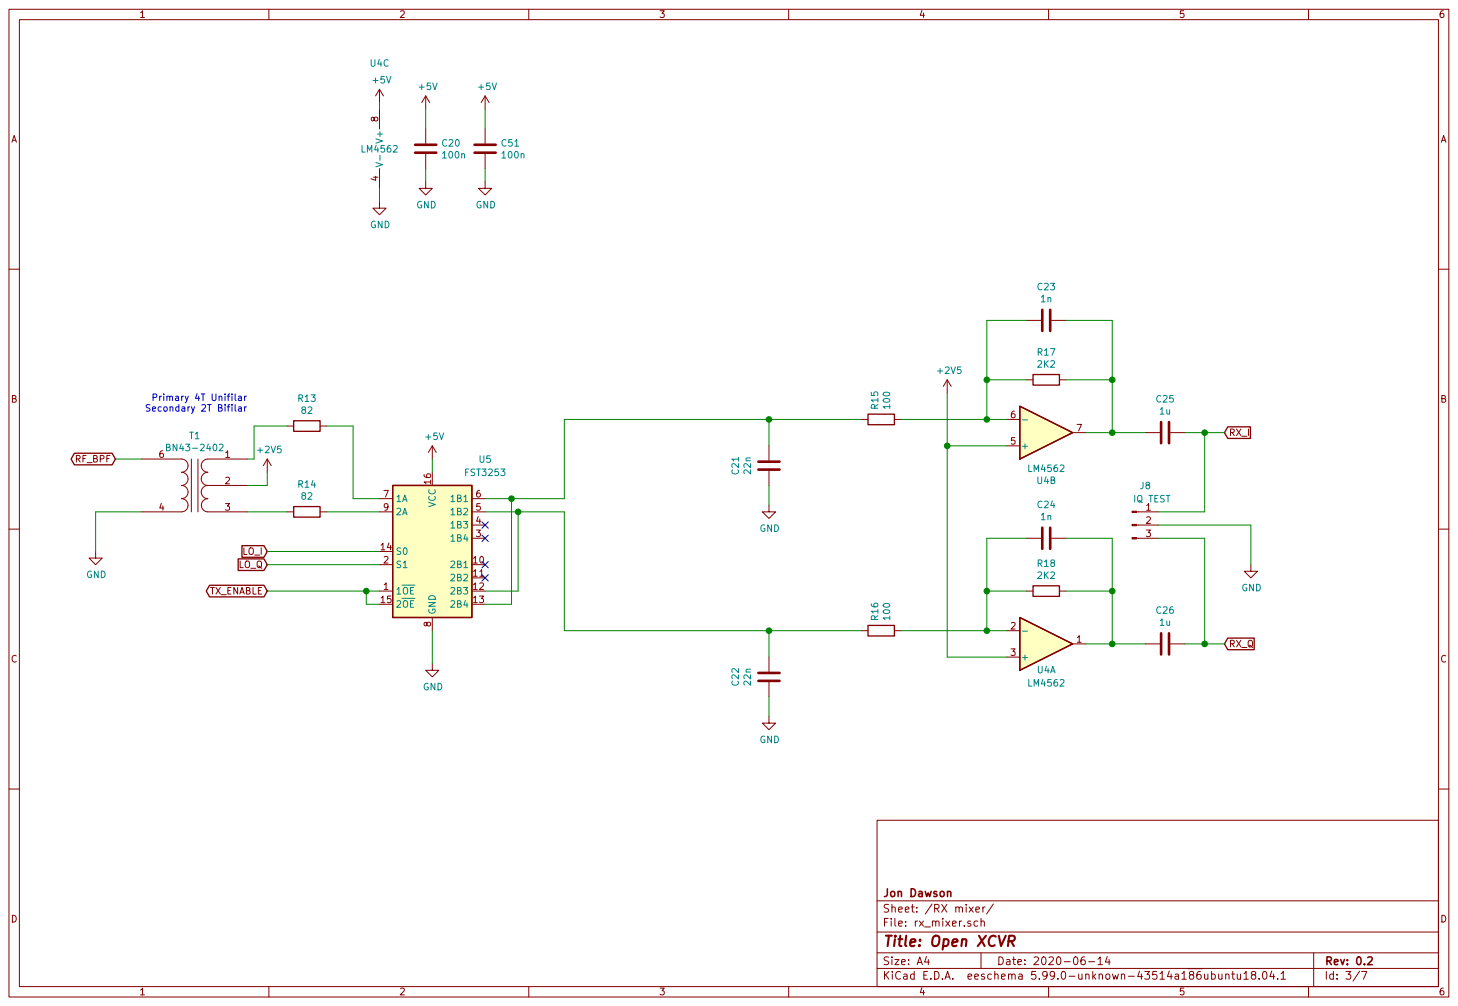
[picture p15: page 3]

Id: 3/7 Title: Open XCVR

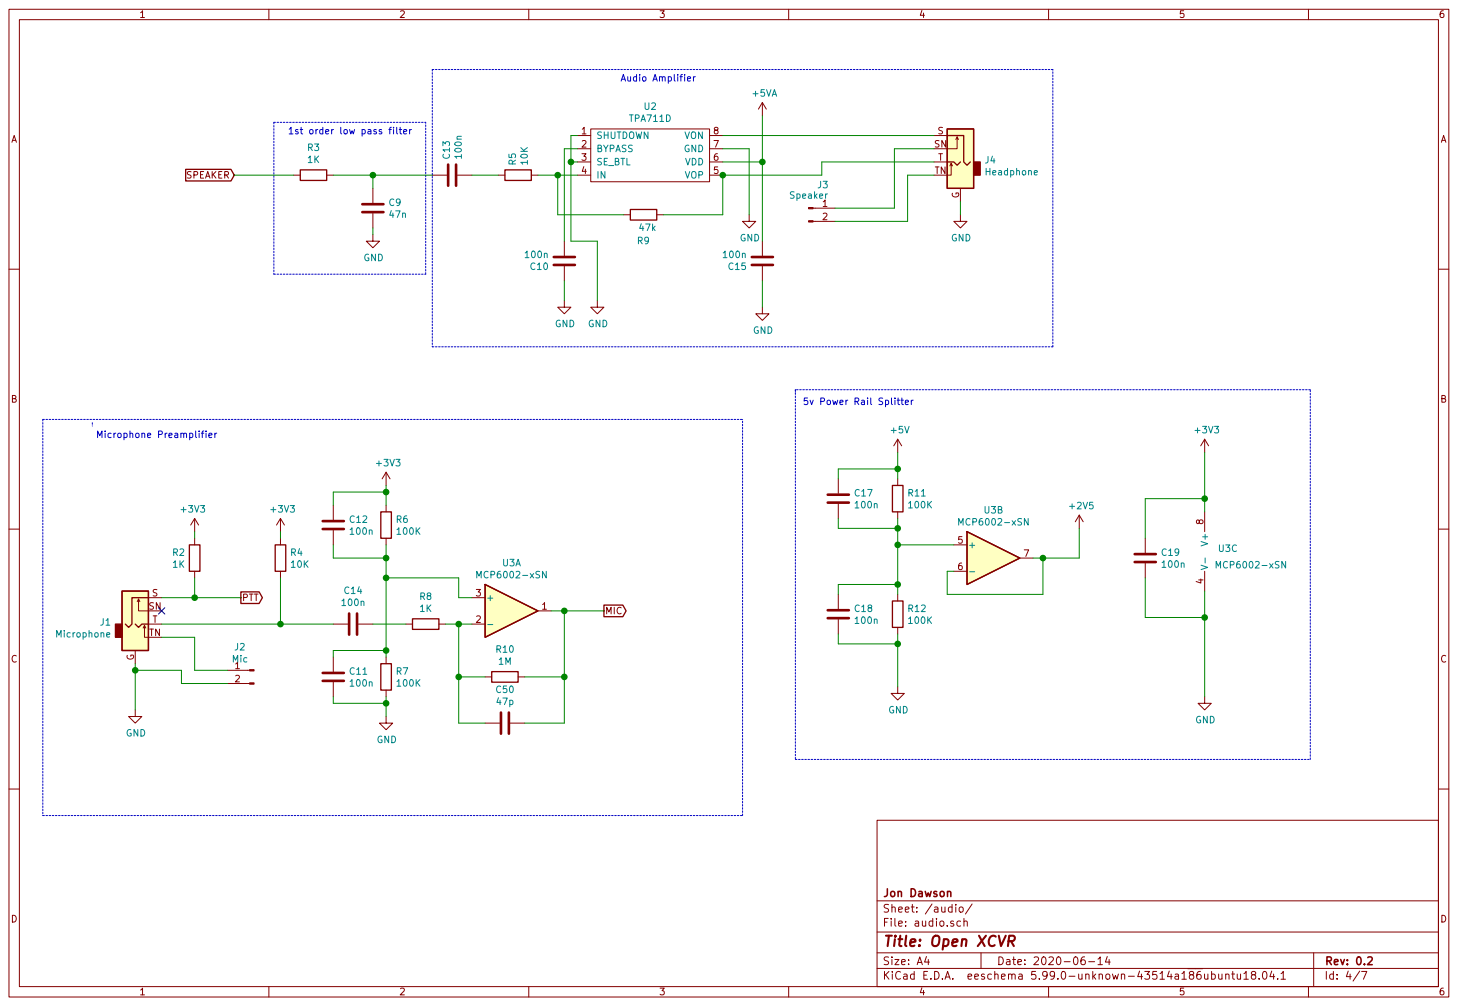
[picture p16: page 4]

1st order low pass filter

File: audio.sch Sheet: /audio/ Jon Dawson

Id: 4/7 Title: Open XCVR

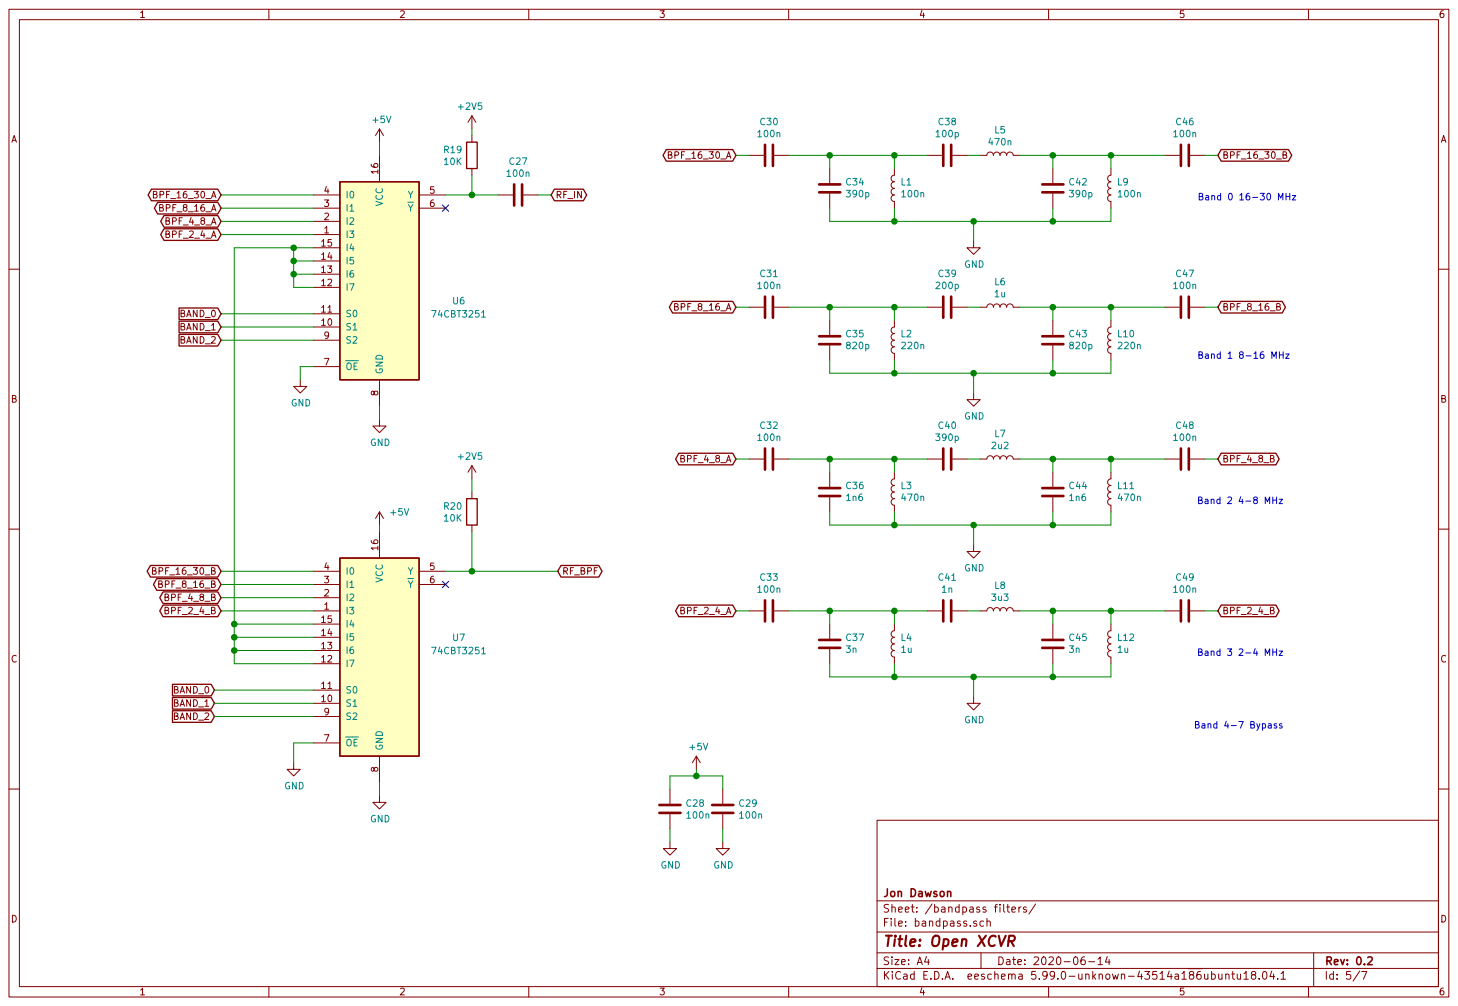
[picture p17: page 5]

Band 0 16-30 MHz Band 3 2-4 MHz Band 2 4-8 MHz

Sheet: /bandpass filters/ Jon DawsonC41

File: bandpass.sch
Id: 5/7 Title: Open XCVR

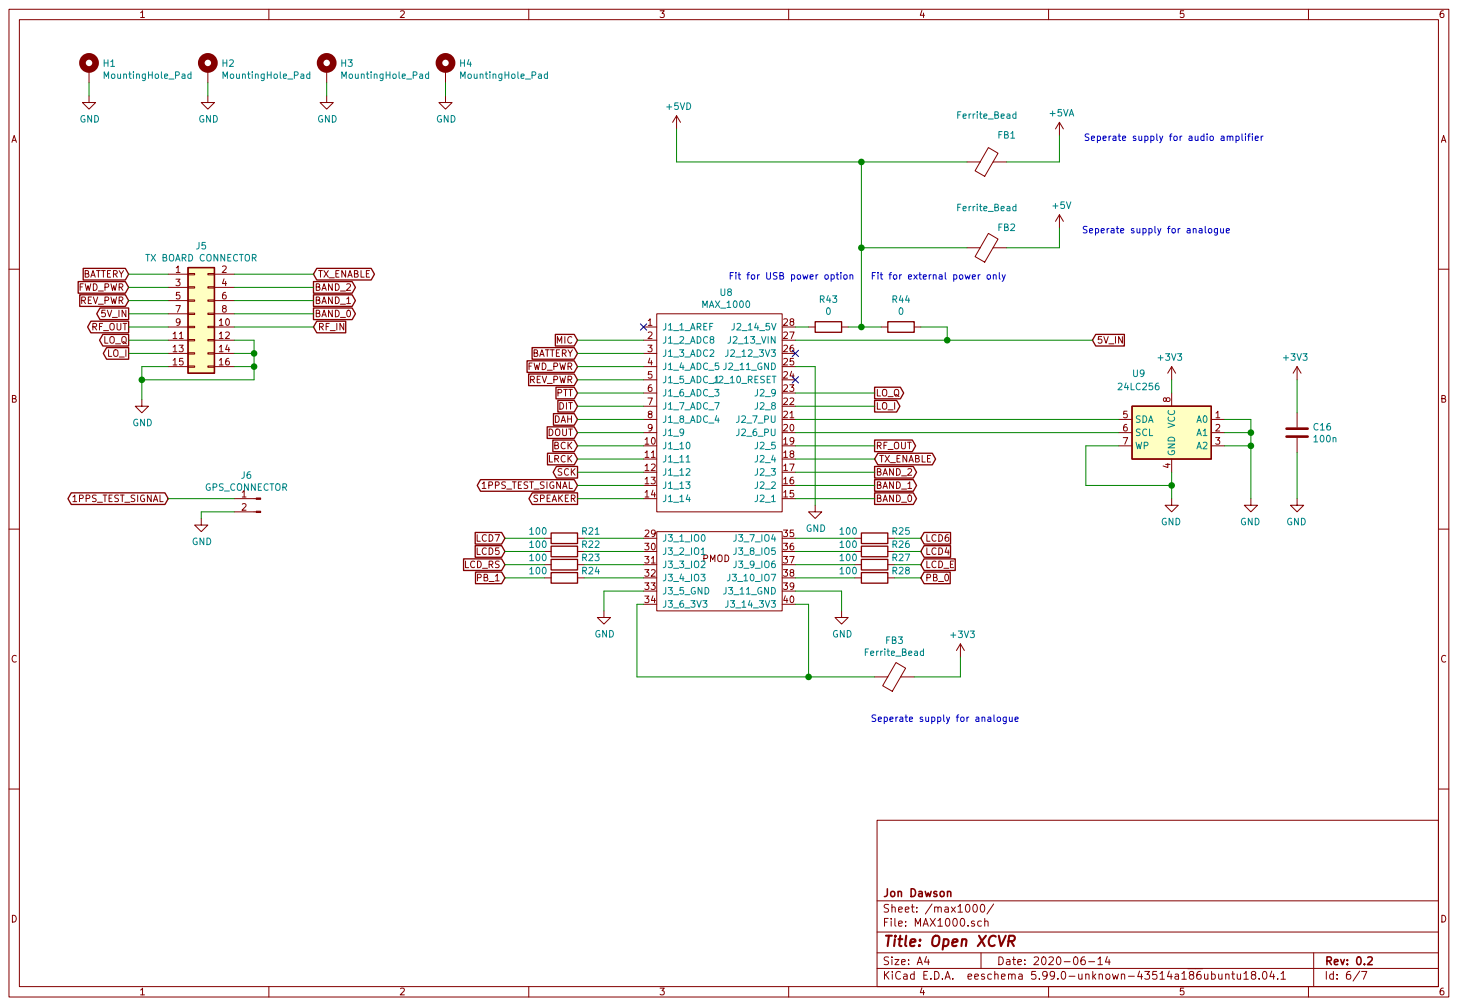
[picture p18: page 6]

Seperate supply for audio amplifier

Seperate supply for analogue

LCD6 Fit for USB power option

Fit for external power only

File: MAX1000.sch Sheet: /max1000/ Jon Dawson GND

4 SDA 5 SCL 6 WP 7 VCC

Id: 6/7 Title: Open XCVR


File: user_interface.sch Sheet: /user interface/ Jon Dawson

Id: 7/7 Title: Open XCVR

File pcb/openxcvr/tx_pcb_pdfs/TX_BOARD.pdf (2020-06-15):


Sheet: low pass filters File: LPF.sch Sheet: transmit receive switching File: TX_RX.sch

Sheet: transmit power amplifier

File: TX_BOARD.sch Sheet: / Jon Dawson

Id: 1/4 Title: Open XCVR


Envelope (audio) switching amplifier

Sheet: /transmit power amplifier/ Jon Dawson R21

File: tx_pa.sch
Id: 2/4 Title: Open XCVR


File: LPF.sch Sheet: /low pass filters/ Jon Dawson

Id: 3/4 Title: Open XCVR


Sheet: /transmit receive switching / Jon Dawson

File: TX_RX.sch
Id: 4/4 Title: Open XCVR

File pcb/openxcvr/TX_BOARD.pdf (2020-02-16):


File: LPF.sch Sheet: TX_RX

File: TX_BOARD.sch Sheet: / Jon Dawson

Id: 1/3 Title: Open XCVR


Id: 2/3 Title: File: LPF.sch Sheet: /LPF/


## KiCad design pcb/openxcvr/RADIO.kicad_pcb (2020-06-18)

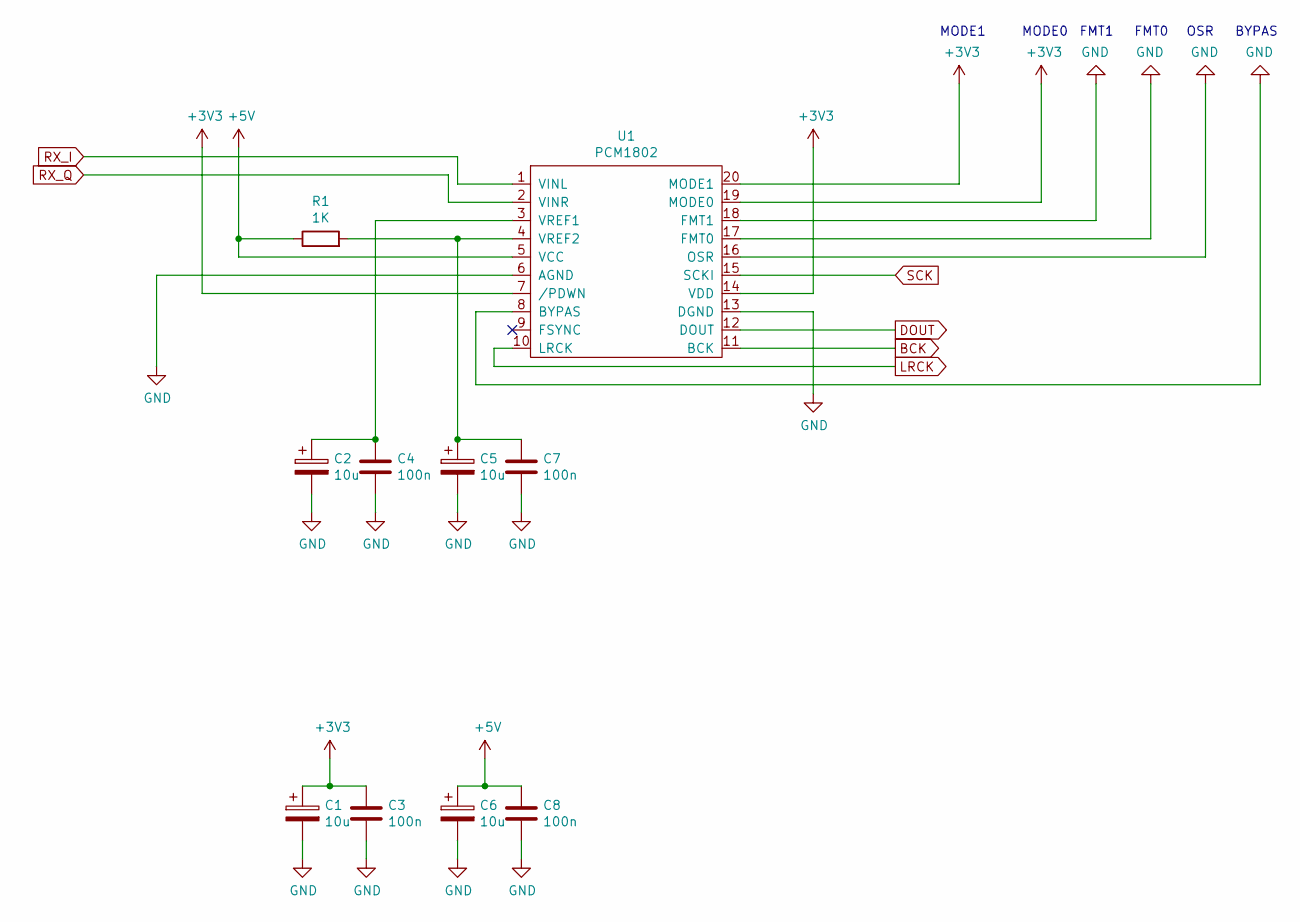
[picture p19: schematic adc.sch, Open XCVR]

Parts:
C1, C2, C5, C6: 10u; CP_EIA-3216-18_Kemet-A
C3, C4, C7, C8: 100n; C_0805_2012Metric
R1: 1K; R_0805_2012Metric
U1: PCM1802; SSOP-20_5.3x7.2mm_P0.65mm

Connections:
+3V3: C1.1, C3.1, U1.7 (/PDWN), U1.14 (VDD), U1.19 (MODE0), U1.20 (MODE1); also elsewhere on the board
+5V: C6.1, C8.1, R1.1, U1.5 (VCC); also elsewhere on the board
BCK: U1.11 (BCK); also elsewhere on the board
DOUT: U1.12 (DOUT); also elsewhere on the board
GND: C1.2, C2.2, C3.2, C4.2, C5.2, C6.2, C7.2, C8.2, U1.6 (AGND), U1.8 (BYPAS), U1.13 (DGND), U1.16 (OSR), U1.17 (FMT0), U1.18 (FMT1); also elsewhere on the board
LRCK: U1.10 (LRCK); also elsewhere on the board
unnamed: C2.1, C4.1, U1.3 (VREF1)
unnamed: C5.1, C7.1, R1.2, U1.4 (VREF2)
RX_I: U1.1 (VINL); also elsewhere on the board
RX_Q: U1.2 (VINR); also elsewhere on the board
SCK: U1.15 (SCKI); also elsewhere on the board

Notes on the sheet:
MODE1
MODE0
FMT1
FMT0
OSR
BYPAS

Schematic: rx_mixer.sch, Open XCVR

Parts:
C20, C51: 100n; C_0805_2012Metric
C21, C22: 22n; C_0805_2012Metric
C23, C24: 1n; C_0805_2012Metric
C25, C26: 1u; C_0805_2012Metric
J8: IQ TEST; PinHeader_1x03_P2.54mm_Vertical
R13, R14: 82; R_0805_2012Metric
R15, R16: 100; R_0805_2012Metric
R17, R18: 2K2; R_0805_2012Metric
T1: BN43-2402; bn43-2402-transformer
U4: LM4562; SOIC-8_3.9x4.9mm_P1.27mm
U5: FST3253; SOIC-16_3.9x9.9mm_P1.27mm

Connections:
+2V5: T1.2 (SC), U4.3, U4.5; also elsewhere on the board
+5V: C20.1, C51.1, U4.8, U5.16 (VCC); also elsewhere on the board
GND: C20.2, C21.1, C22.1, C51.2, J8.2, T1.4 (AB), U4.4, U5.8 (GND); also elsewhere on the board
LO_I: U5.14 (S0); also elsewhere on the board
LO_Q: U5.2 (S1); also elsewhere on the board
unnamed: C21.2, R15.2, U5.6 (1B1), U5.13 (2B4)
unnamed: C22.2, R16.2, U5.5 (1B2), U5.12 (2B3)
unnamed: C23.1, R15.1, R17.1, U4.6
unnamed: C23.2, C25.1, R17.2, U4.7
unnamed: C24.1, R16.1, R18.1, U4.2
unnamed: C24.2, C26.1, R18.2, U4.1
unnamed: R13.1, T1.1 (SB)
unnamed: R13.2, U5.7 (1A)
unnamed: R14.1, T1.3 (SA)
unnamed: R14.2, U5.9 (2A)
RF_BPF: T1.6 (AA); also elsewhere on the board
RX_I: C25.2, J8.1; also elsewhere on the board
RX_Q: C26.2, J8.3; also elsewhere on the board
TX_ENABLE: U5.1 (1~OE), U5.15 (2~OE); also elsewhere on the board

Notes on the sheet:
Primary 4T Unifilar Secondary 2T Bifilar

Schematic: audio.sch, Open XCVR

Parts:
C9: 47n; C_0805_2012Metric
C10, C11, C12, C13, C14, C15, C17, C18, C19, C52: 100n; C_0805_2012Metric
C50: 47p; C_0805_2012Metric
C53: 100u; CP_EIA-7343-31_Kemet-D
J1: Microphone; jack3.5mm switched
J2: Mic; PinHeader_1x02_P2.54mm_Vertical
J3: Speaker; PinHeader_1x02_P2.54mm_Vertical
J4: Headphone; jack3.5mm switched
R2, R3, R8, R47: 1K; R_0805_2012Metric
R4, R5: 10K; R_0805_2012Metric
R6, R7, R11, R12, R45, R46: 100K; R_0805_2012Metric
R9: 47k; R_0805_2012Metric
R10: 1M; R_0805_2012Metric
U2: TPA711D; SOIC-8_3.9x4.9mm_P1.27mm
U3: MCP6002-xSN; SOIC-8_3.9x4.9mm_P1.27mm

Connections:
+2V5: U3.6, U3.7; also elsewhere on the board
+3V3: C12.1, C19.1, R2.1, R4.1, R6.1, U3.8; also elsewhere on the board
+5V: C17.1, R11.1; also elsewhere on the board
+5VA: C15.2, R46.2, U2.6 (VDD); also elsewhere on the board
GND: C9.2, C10.1, C11.2, C15.1, C18.2, C19.2, C52.1, J1.G, J2.2, J4.G, R7.2, R12.2, R47.1, U2.1 (SHUTDOWN), U2.7 (GND), U3.4; also elsewhere on the board
MIC: C50.2, R10.2, U3.1; also elsewhere on the board
unnamed: C10.2, U2.2 (BYPASS)
unnamed: C11.1, C12.2, R6.2, R7.1, U3.3
unnamed: C9.1, C13.1, R3.2
unnamed: C13.2, R5.1
unnamed: C14.1, J1.T, R4.2
unnamed: C14.2, R8.1
unnamed: C17.2, C18.1, R11.2, R12.1, U3.5
unnamed: C50.1, R8.2, R10.1, U3.2
unnamed: C52.2, R45.2, U2.3 (SE_BTL)
unnamed: C53.1, J3.2, R9.2, U2.5 (VOP)
unnamed: C53.2, J4.S, J4.T, R47.2
unnamed: J1.TN, J2.1
unnamed: J3.1, U2.8 (VON)
unnamed: J4.TN, R45.1, R46.1
unnamed: R5.2, R9.1, U2.4 (IN)
PTT: J1.S, R2.2; also elsewhere on the board
SPEAKER: R3.1; also elsewhere on the board

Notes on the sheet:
Microphone Preamplifier
1st order low pass filter
Audio Amplifier
5v Power Rail Splitter

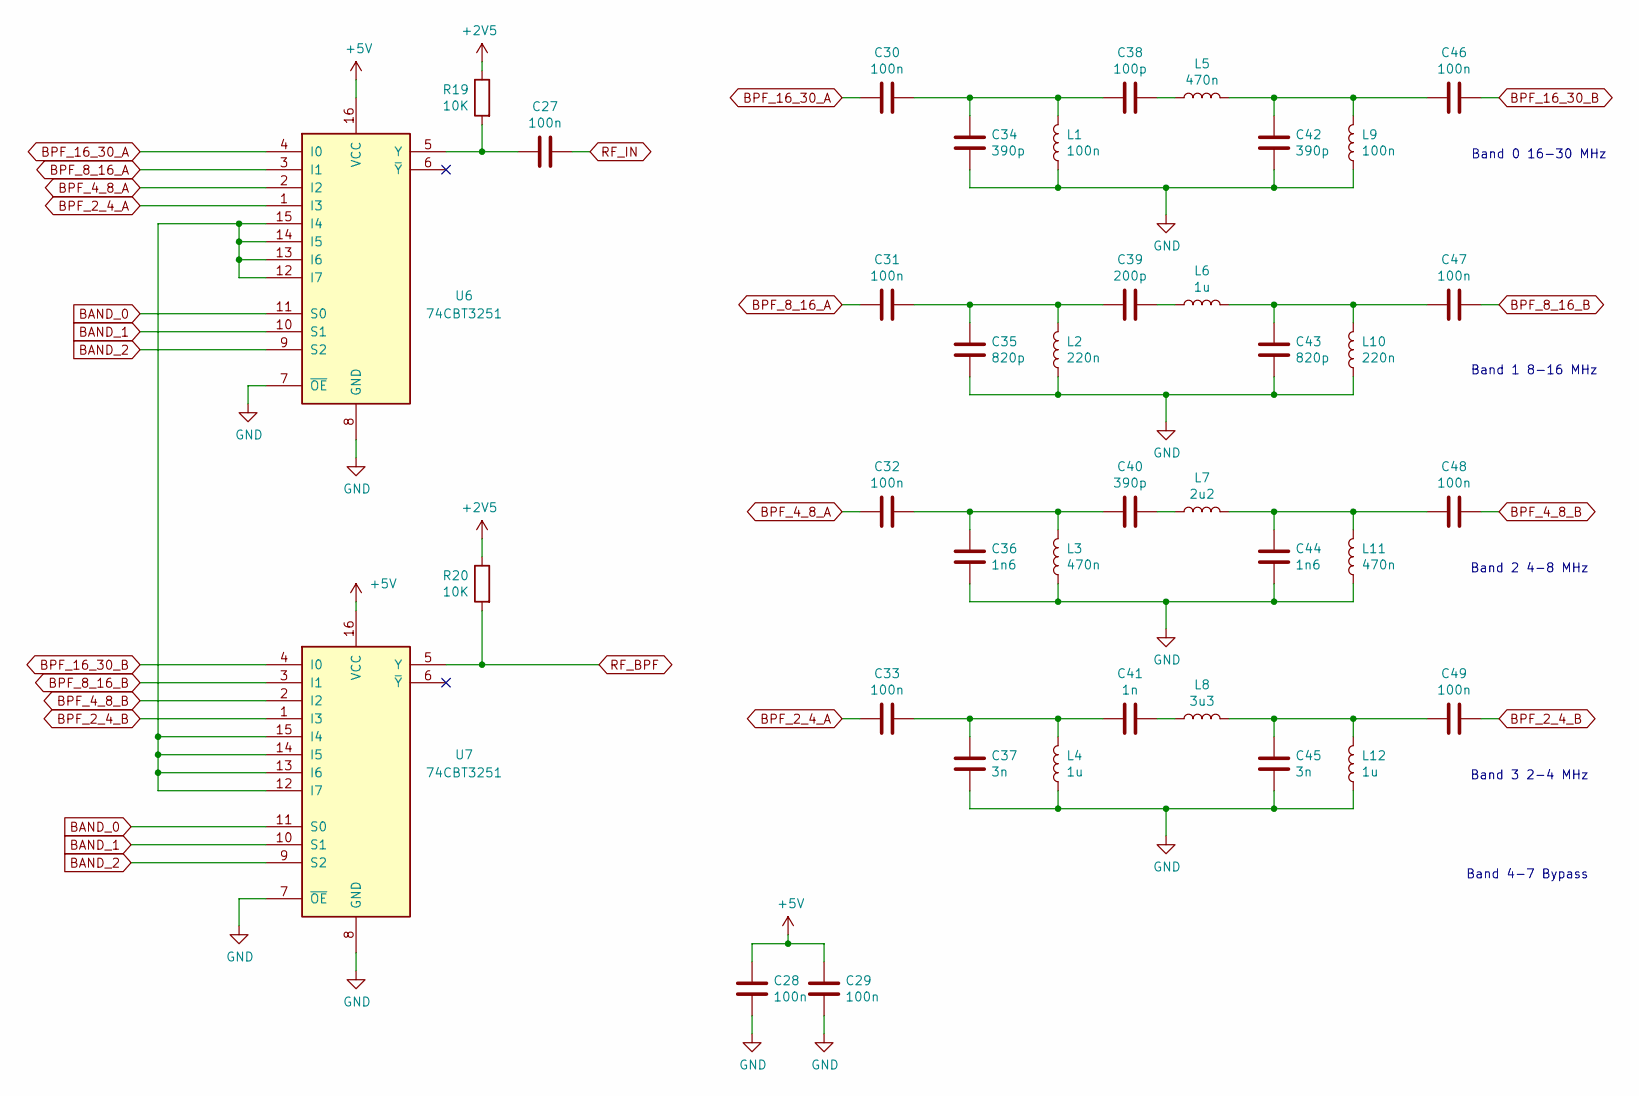
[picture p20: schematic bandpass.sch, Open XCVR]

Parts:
C27, C28, C29, C30, C31, C32, C33, C46, C47, C48, C49: 100n; C_0805_2012Metric
C34, C40, C42: 390p; C_0805_2012Metric
C35, C43: 820p; C_0805_2012Metric
C36, C44: 1n6; C_0805_2012Metric
C37, C45: 3n; C_0805_2012Metric
C38: 100p; C_0805_2012Metric
C39: 200p; C_0805_2012Metric
C41: 1n; C_0805_2012Metric
L1, L9: 100n; L_TDK_NLV32_3.2x2.5mm
L2, L10: 220n; L_TDK_NLV32_3.2x2.5mm
L3, L5, L11: 470n; L_TDK_NLV32_3.2x2.5mm
L4, L6, L12: 1u; L_TDK_NLV32_3.2x2.5mm
L7: 2u2; L_TDK_NLV32_3.2x2.5mm
L8: 3u3; L_TDK_NLV32_3.2x2.5mm
R19, R20: 10K; R_0805_2012Metric
U6, U7: 74CBT3251; SOIC-16_3.9x9.9mm_P1.27mm

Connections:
+2V5: R19.1, R20.1; also elsewhere on the board
+5V: C28.1, C29.1, U6.16 (VCC), U7.16 (VCC); also elsewhere on the board
BAND_0: U6.11 (S0), U7.11 (S0); also elsewhere on the board
BAND_1: U6.10 (S1), U7.10 (S1); also elsewhere on the board
BAND_2: U6.9 (S2), U7.9 (S2); also elsewhere on the board
BPF_2_4_A: C33.1, U6.1 (I3)
BPF_2_4_B: C49.2, U7.1 (I3)
BPF_4_8_A: C32.1, U6.2 (I2)
BPF_4_8_B: C48.2, U7.2 (I2)
BPF_8_16_A: C31.1, U6.3 (I1)
BPF_8_16_B: C47.2, U7.3 (I1)
BPF_16_30_A: C30.1, U6.4 (I0)
BPF_16_30_B: C46.2, U7.4 (I0)
GND: C28.2, C29.2, C34.1, C35.1, C36.1, C37.1, C42.1, C43.1, C44.1, C45.1, L1.1, L2.1, L3.1, L4.1, L9.1, L10.1, L11.1, L12.1, U6.7 (~OE), U6.8 (GND), U7.7 (~OE), U7.8 (GND); also elsewhere on the board
unnamed: C27.2, R19.2, U6.5 (Y)
unnamed: C30.2, C34.2, C38.1, L1.2
unnamed: C31.2, C35.2, C39.1, L2.2
unnamed: C32.2, C36.2, C40.1, L3.2
unnamed: C33.2, C37.2, C41.1, L4.2
unnamed: C38.2, L5.1
unnamed: C39.2, L6.1
unnamed: C40.2, L7.1
unnamed: C41.2, L8.1
unnamed: C42.2, C46.1, L5.2, L9.2
unnamed: C43.2, C47.1, L6.2, L10.2
unnamed: C44.2, C48.1, L7.2, L11.2
unnamed: C45.2, C49.1, L8.2, L12.2
unnamed: U6.12 (I7), U6.13 (I6), U6.14 (I5), U6.15 (I4), U7.12 (I7), U7.13 (I6), U7.14 (I5), U7.15 (I4)
RF_BPF: R20.2, U7.5 (Y); also elsewhere on the board
RF_IN: C27.1; also elsewhere on the board

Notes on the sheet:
Band 2 4-8 MHz
Band 3 2-4 MHz
Band 4-7 Bypass
Band 1 8-16 MHz
Band 0 16-30 MHz

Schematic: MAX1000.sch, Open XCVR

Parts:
C16: 100n; C_0805_2012Metric
FB1, FB2, FB3: Ferrite_Bead; L_0805_2012Metric
H1, H2, H3, H4: MountingHole_Pad; MountingHole_3.2mm_M3_Pad
J5: TX BOARD CONNECTOR; PinHeader_2x08_P2.54mm_Vertical
J6: GPS_CONNECTOR; PinHeader_1x02_P2.54mm_Vertical
R21, R22, R23, R24, R25, R26, R27, R28: 100; R_0805_2012Metric
R43, R44: 0; R_0805_2012Metric
U8: MAX_1000; max1000
U9: 24LC256; SOIC-8_3.9x4.9mm_P1.27mm

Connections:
1PPS_TEST_SIGNAL: J6.1, U8.13 (J1_13)
5V_IN: J5.7, R44.2, U8.27 (J2_13_VIN)
+3V3: C16.1, FB3.2, U9.8; also elsewhere on the board
+5V: FB2.2; also elsewhere on the board
+5VA: FB1.2; also elsewhere on the board
+5VD: FB1.1, FB2.1, R43.2, R44.1; also elsewhere on the board
BAND_0: J5.8, U8.15 (J2_1); also elsewhere on the board
BAND_1: J5.6, U8.16 (J2_2); also elsewhere on the board
BAND_2: J5.4, U8.17 (J2_3); also elsewhere on the board
BATTERY: J5.1, U8.3 (J1_3_ADC2)
BCK: U8.10 (J1_10); also elsewhere on the board
DAH: U8.8 (J1_8_ADC_4); also elsewhere on the board
DIT: U8.7 (J1_7_ADC_7); also elsewhere on the board
DOUT: U8.9 (J1_9); also elsewhere on the board
FWD_PWR: J5.3, U8.4 (J1_4_ADC_5)
GND: C16.2, H1.1, H2.1, H3.1, H4.1, J5.12, J5.14, J5.15, J5.16, J6.2, U8.25 (J2_11_GND), U8.33 (J3_5_GND), U8.39 (J3_11_GND), U9.1, U9.2, U9.3, U9.4, U9.7; also elsewhere on the board
LCD4: R26.2; also elsewhere on the board
LCD5: R22.1; also elsewhere on the board
LCD6: R25.2; also elsewhere on the board
LCD7: R21.1; also elsewhere on the board
LCD_E: R27.2; also elsewhere on the board
LCD_RS: R23.1; also elsewhere on the board
LO_I: J5.13, U8.22 (J2_8); also elsewhere on the board
LO_Q: J5.11, U8.23 (J2_9); also elsewhere on the board
LRCK: U8.11 (J1_11); also elsewhere on the board
MIC: U8.2 (J1_2_ADC8); also elsewhere on the board
unnamed: FB3.1, U8.34 (J3_6_3V3), U8.40 (J3_14_3V3)
unnamed: R21.2, U8.29 (J3_1_IO0)
unnamed: R22.2, U8.30 (J3_2_IO1)
unnamed: R23.2, U8.31 (J3_3_IO2)
unnamed: R24.2, U8.32 (J3_4_IO3)
unnamed: R25.1, U8.35 (J3_7_IO4)
unnamed: R26.1, U8.36 (J3_8_IO5)
unnamed: R27.1, U8.37 (J3_9_IO6)
unnamed: R28.1, U8.38 (J3_10_IO7)
unnamed: R43.1, U8.28 (J2_14_5V)
unnamed: U8.20 (J2_6_PU), U9.6
unnamed: U8.21 (J2_7_PU), U9.5
PB_0: R28.2; also elsewhere on the board
PB_1: R24.1; also elsewhere on the board
PTT: U8.6 (J1_6_ADC_3); also elsewhere on the board
REV_PWR: J5.5, U8.5 (J1_5_ADC_1)
RF_IN: J5.10; also elsewhere on the board
RF_OUT: J5.9, U8.19 (J2_5)
SCK: U8.12 (J1_12); also elsewhere on the board
SPEAKER: U8.14 (J1_14); also elsewhere on the board
TX_ENABLE: J5.2, U8.18 (J2_4); also elsewhere on the board

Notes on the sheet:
Fit for USB power option
Fit for external power only
Seperate supply for analogue
Seperate supply for audio amplifier

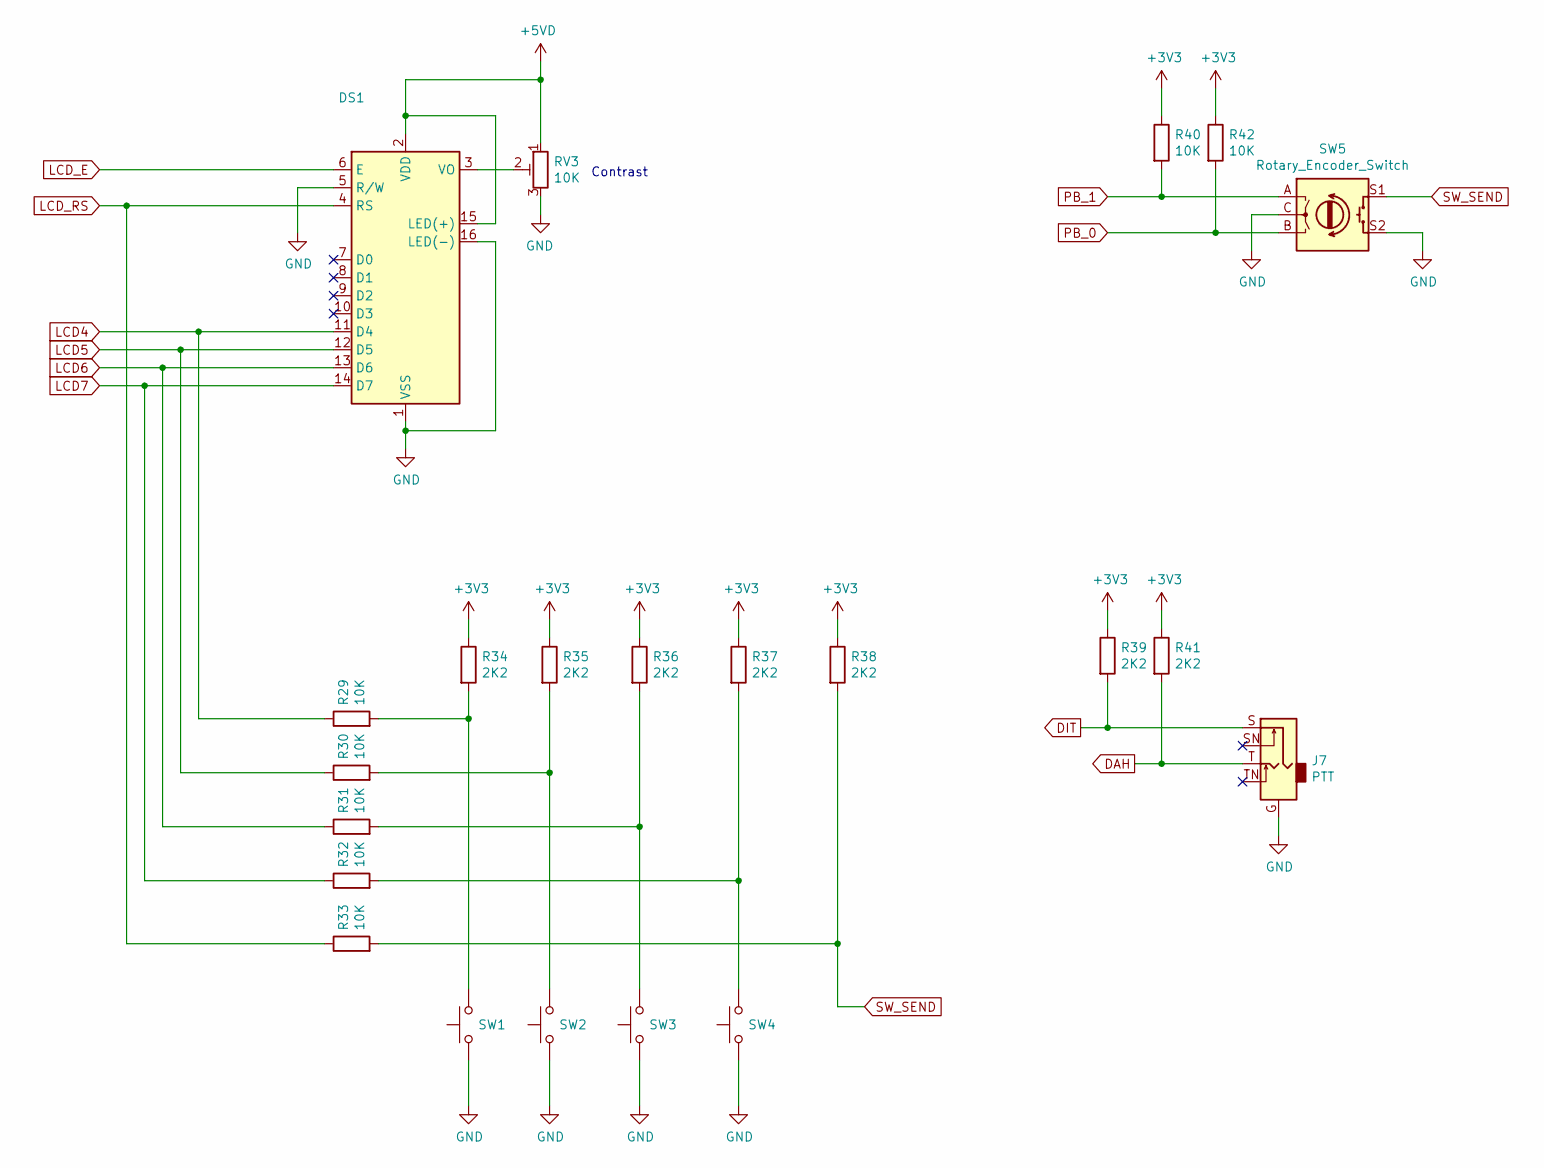
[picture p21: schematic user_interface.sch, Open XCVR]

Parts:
DS1: WC1602A
J7: PTT; jack3.5mm switched
R29, R30, R31, R32, R33, R40, R42: 10K; R_0805_2012Metric
R34, R35, R36, R37, R38, R39, R41: 2K2; R_0805_2012Metric
RV3: 10K; Potentiometer_Piher_PT-6-V_Vertical
SW1, SW2, SW3, SW4: SW_Push; SW_PUSH_6mm
SW5: Rotary_Encoder_Switch; RotaryEncoder_Alps_EC12E-Switch_Vertical_H20mm

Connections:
+3V3: R34.1, R35.1, R36.1, R37.1, R38.1, R39.1, R40.1, R41.1, R42.1; also elsewhere on the board
+5VD: DS1.2 (VDD), DS1.15 (LED(+)), RV3.1; also elsewhere on the board
DAH: J7.T, R41.2; also elsewhere on the board
DIT: J7.S, R39.2; also elsewhere on the board
GND: DS1.1 (VSS), DS1.5 (R/W), DS1.16 (LED(-)), J7.G, RV3.3, SW1.1, SW2.1, SW3.1, SW4.1, SW5.C, SW5.S2; also elsewhere on the board
LCD4: DS1.11 (D4), R29.1; also elsewhere on the board
LCD5: DS1.12 (D5), R30.1; also elsewhere on the board
LCD6: DS1.13 (D6), R31.1; also elsewhere on the board
LCD7: DS1.14 (D7), R32.1; also elsewhere on the board
LCD_E: DS1.6 (E); also elsewhere on the board
LCD_RS: DS1.4 (RS), R33.1; also elsewhere on the board
unnamed: DS1.3 (VO), RV3.2
unnamed: R29.2, R34.2, SW1.2
unnamed: R30.2, R35.2, SW2.2
unnamed: R31.2, R36.2, SW3.2
unnamed: R32.2, R37.2, SW4.2
PB_0: R42.2, SW5.B; also elsewhere on the board
PB_1: R40.2, SW5.A; also elsewhere on the board
SW_SEND: R33.2, R38.2, SW5.S1

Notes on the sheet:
Contrast

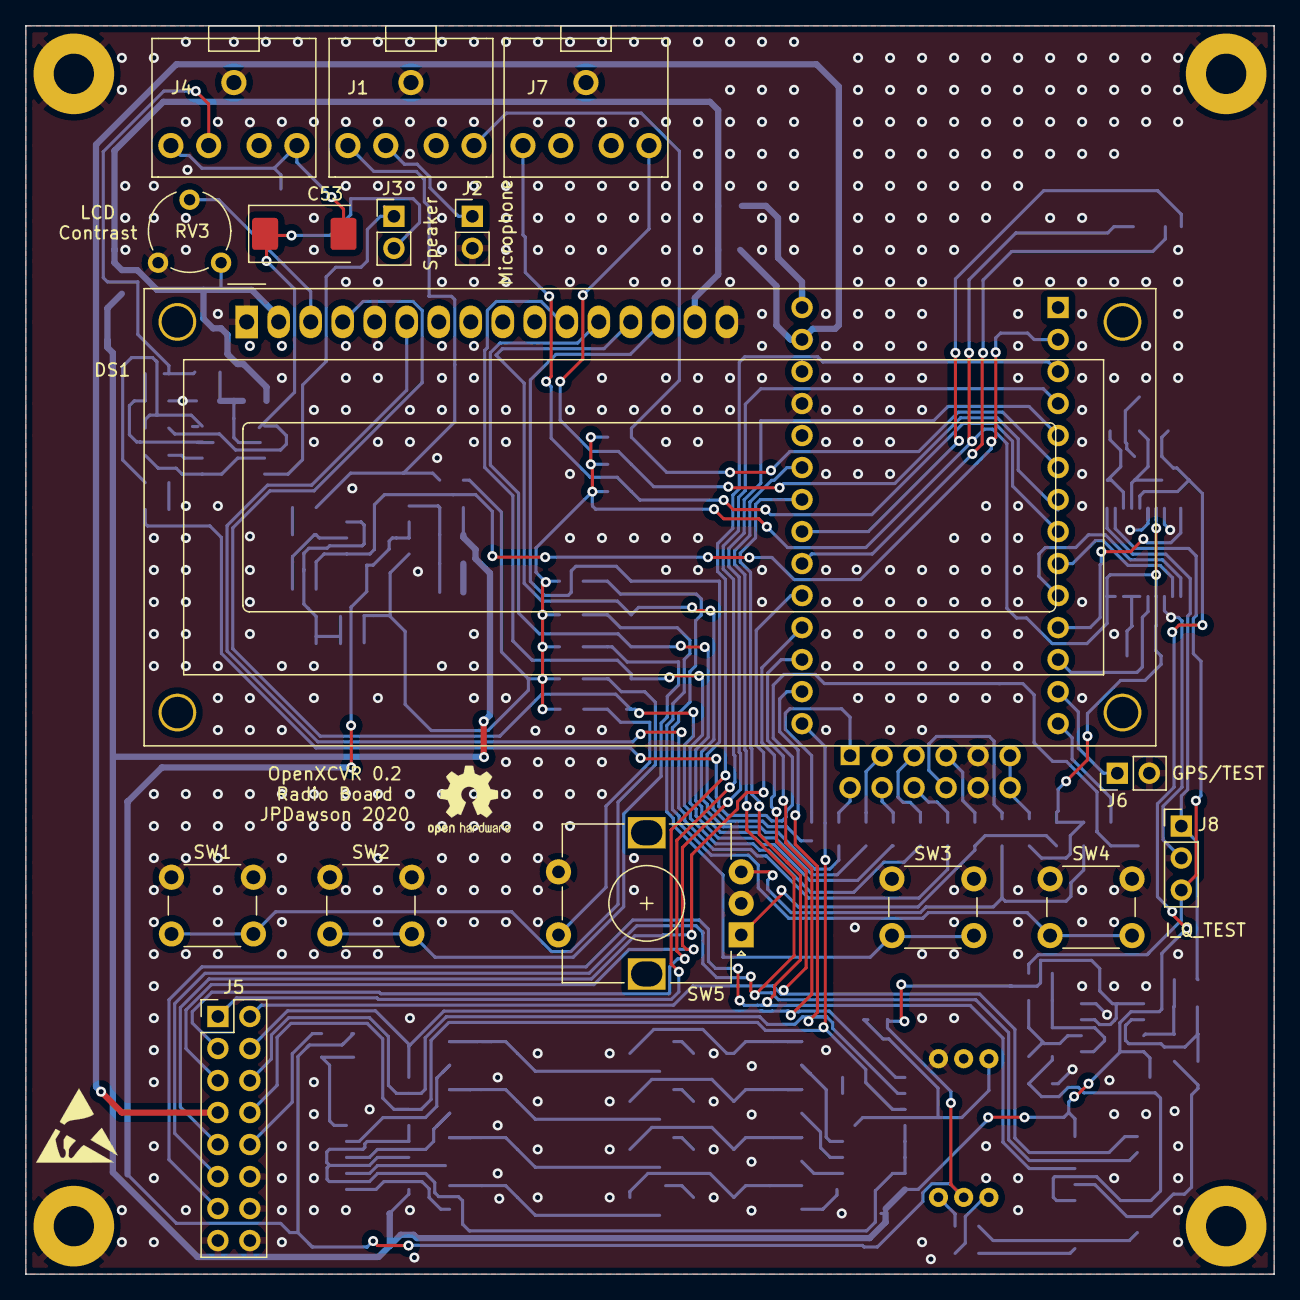
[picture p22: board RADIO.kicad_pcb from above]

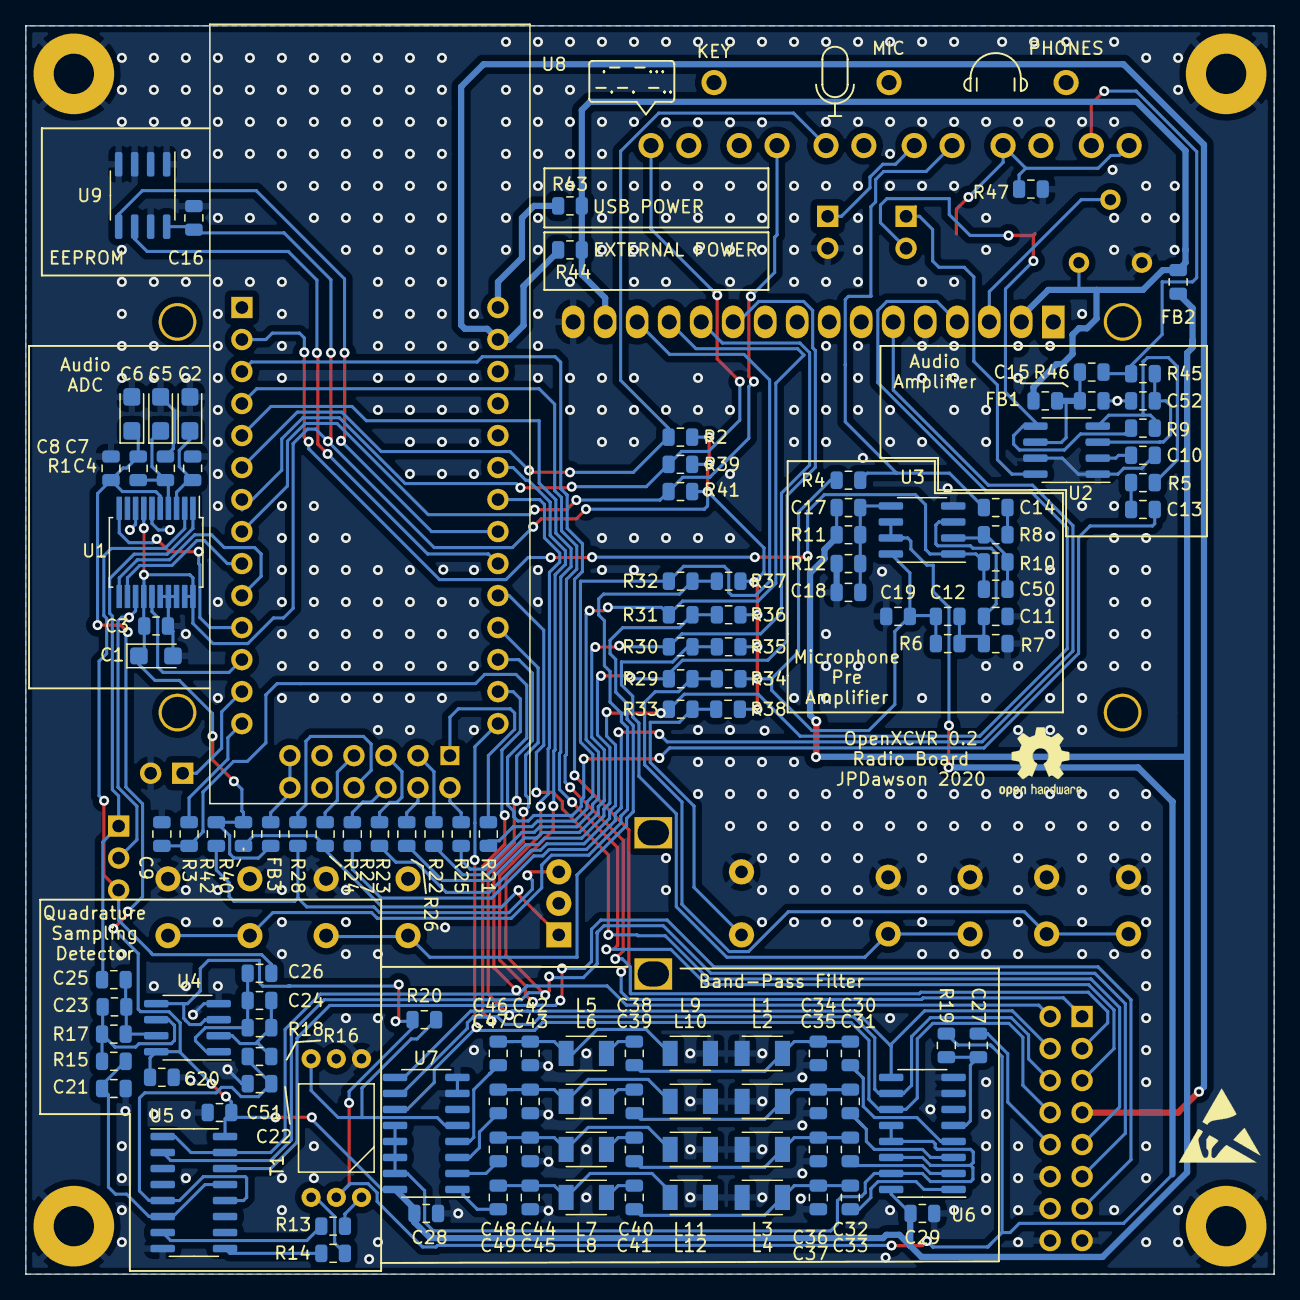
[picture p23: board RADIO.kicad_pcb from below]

Board: 2 copper layers, 99.1 x 99.1 mm, 144 parts (124 on the bottom side), 106 nets.

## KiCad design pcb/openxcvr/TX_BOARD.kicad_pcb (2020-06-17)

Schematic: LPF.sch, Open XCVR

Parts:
C1, C13: 56p; C_0805_2012Metric
C2, C14: 180p; C_0805_2012Metric
C3, C15: 270p; C_0805_2012Metric
C4, C16: 470p; C_0805_2012Metric
C5, C9: 150p; C_0805_2012Metric
C6, C10: 390p; C_0805_2012Metric
C7, C11: 680p; C_0805_2012Metric
C8, C12: 1.2n; C_0805_2012Metric
D1, D2, D3: 1N4148W; D_SOD-123
H1, H2, H3, H4: MountingHole_Pad; MountingHole_3.2mm_M3_Pad
K1, K2, K3: G5V-2; Relay_DPDT_Omron_G5V-2
L1, L9: 303n; FT37-INDUCTOR
L2, L10: 773n; FT37-INDUCTOR
L3, L11: 1.380u; FT37-INDUCTOR
L4, L12: 2.434u; FT37-INDUCTOR
L5: 382n; FT37-INDUCTOR
L6: 904n; FT37-INDUCTOR
L7: 1.698u; FT37-INDUCTOR
L8: 3.012u; FT37-INDUCTOR
Q1, Q2: BS170; TO-92_Inline
R1, R2: 10K; R_0805_2012Metric

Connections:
BAND_0: Q2.2, R2.1; also elsewhere on the board
BAND_1: Q1.2, R1.1; also elsewhere on the board
GND: C1.2, C2.2, C3.2, C4.2, C5.2, C6.2, C7.2, C8.2, C9.2, C10.2, C11.2, C12.2, C13.2, C14.2, C15.2, C16.2, H1.1, H2.1, H3.1, H4.1, Q1.3, Q2.3, R1.2, R2.2; also elsewhere on the board
LPF_BAND_0_A: C1.1, K2.11, L1.1
LPF_BAND_0_B: C13.1, K3.6, L9.2
LPF_BAND_1_A: C2.1, K2.9, L2.1
LPF_BAND_1_B: C14.1, K3.8, L10.2
LPF_BAND_2_A: C3.1, K2.6, L3.1
LPF_BAND_2_B: C15.1, K3.11, L11.2
LPF_BAND_3_A: C4.1, K2.8, L4.1
LPF_BAND_3_B: C16.1, K3.9, L12.2
LPF_ENABLE: D1.1, D2.1, D3.1, K1.1, K2.1, K3.1; also elsewhere on the board
unnamed: C5.1, L1.2, L5.1
unnamed: C6.1, L2.2, L6.1
unnamed: C7.1, L3.2, L7.1
unnamed: C8.1, L4.2, L8.1
unnamed: C9.1, L5.2, L9.1
unnamed: C10.1, L6.2, L10.1
unnamed: C11.1, L7.2, L11.1
unnamed: C12.1, L8.2, L12.1
unnamed: D1.2, K1.16, Q1.1
unnamed: D2.2, D3.2, K2.16, K3.16, Q2.1
unnamed: K1.6, K2.13
unnamed: K1.8, K2.4
unnamed: K1.9, K3.13
unnamed: K1.11, K3.4
PA_OUT: K1.13; also elsewhere on the board
SWR_IN: K1.4; also elsewhere on the board

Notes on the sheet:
10T T37-6
16T T37-6
19T T37-6
25T T37-2
21T T37-6
27T T37-2
11T T37-6
17T T37-6
Fc=31.66MHz (16-30MHz)
Fc=14.4MHz (8-16MHz)
Fc=7.36MHz (4-8MHz)
Fc=4.125MHz (2-4MHz)

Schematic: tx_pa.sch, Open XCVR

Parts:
C21, C26: 68n; C_0805_2012Metric
C22, C23, C24, C27, C28: 100n; C_0805_2012Metric
C25: 220n; C_0805_2012Metric
D7: D_Schottky; D_SOD-106
D8: 51v; D_SOD-123
L13, L14: 100u; L_SMT_INDUCTOR
L15: 44 u; FT50-43 INDUCTOR
Q4, Q5, Q6: BS170; TO-92_Inline
R14, R15: 10; R_0805_2012Metric
R16, R17, R18: 4k7; R_0805_2012Metric
R19, R21: 10k; R_0805_2012Metric
RV1: 10k; Potentiometer_Piher_PT-6-V_Vertical
U4: MCP1406; SOIC-8_3.9x4.9mm_P1.27mm
U5: DMC3056LSS; SOP-8_3.9x4.9mm_P1.27mm
U6: 74AC00; SOIC-14_3.9x8.7mm_P1.27mm

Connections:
+5V: C27.1, RV1.1, U6.14; also elsewhere on the board
+12V: U4.1 (VDD), U4.8 (VDD), U5.1 (S), U5.2 (S), U5.3 (S); also elsewhere on the board
GND: C21.2, C25.2, C26.2, C27.2, D7.2 (A), D8.2 (A), Q4.3, Q5.3, Q6.3, R19.2, R21.2, RV1.3, U4.4 (GND), U4.5 (GND), U6.7; also elsewhere on the board
LO_I: R21.1, U6.12; also elsewhere on the board
unnamed: C21.1, D7.1 (K), L13.1, U5.5 (D), U5.6 (D), U5.7 (D), U5.8 (D)
unnamed: C22.1, U6.3
unnamed: C22.2, Q4.2, R16.1
unnamed: C23.1, U6.6
unnamed: C23.2, Q5.2, R17.1
unnamed: C24.1, U6.8
unnamed: C24.2, Q6.2, R18.1
unnamed: C25.1, L13.2, L14.1
unnamed: C26.1, L14.2, L15.1
unnamed: C28.1, D8.1 (K), L15.2, Q4.1, Q5.1, Q6.1
unnamed: R14.1, R15.1, U4.6 (OUT_N), U4.7 (OUT_N)
unnamed: R14.2, R15.2, U5.4 (G)
unnamed: R16.2, R17.2, R18.2, RV1.2
unnamed: U6.1, U6.2, U6.4, U6.5, U6.9, U6.10, U6.11
PA_OUT: C28.2; also elsewhere on the board
RF_ENVELOPE: R19.1, U4.2 (INPUT); also elsewhere on the board
TX_ENABLE: U6.13; also elsewhere on the board

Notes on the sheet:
Envelope (audio) switching amplifier
FT 50-43 10 Turns
RF switching amplifier

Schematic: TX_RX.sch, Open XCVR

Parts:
C17, C20: 100n; C_0805_2012Metric
C18, C19: 10u; CP_EIA-3216-18_Kemet-A
D4: 1N4148W; D_SOD-123
D5, D6: 1N5711; D_DO-35_SOD27_P7.62mm_Horizontal
J1: Antenna BNC Connector; BNC_Amphenol_B6252HB-NPP3G-50_Horizontal
J2: RADIO BOARD CONNECTOR; PinHeader_2x08_P2.54mm_Vertical
J3: Power Jack; BarrelJack_Horizontal
J4: Battery Connector; PinHeader_1x02_P2.54mm_Vertical
K4: G5V-2; Relay_DPDT_Omron_G5V-2
Q3: BS170; TO-92_Inline
R3: 10K; R_0805_2012Metric
R4, R5, R7, R12, R13: 10k; R_0805_2012Metric
R6, R9, R10, R11: 100; R_0805_2012Metric
R8: 1K; R_0805_2012Metric
SW1: POWER SWITCH; RS PCB Toggle Switch
TR1, TR2: FT50-43Transformer; FT50-43 Transformer
U1: LM7805CV_TO220; TO-220-3_Vertical
U2, U3: to220heatsink; to220 heatsink

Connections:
+5V: C19.1, J2.7, U1.3 (VO); also elsewhere on the board
+12V: C18.1, D4.1, K4.1, K4.9, R7.1, SW1.3 (C), U1.1 (VI); also elsewhere on the board
ANTENNA: J1.1 (In), K4.6, TR1.4
BAND_0: J2.8; also elsewhere on the board
BAND_1: J2.6; also elsewhere on the board
FWD_PWR: J2.3, R4.1
GND: C17.2, C18.2, C19.2, C20.2, J1.2 (Ext), J2.12, J2.14, J2.15, J2.16, J3.2, K4.8, Q3.3, R3.2, R5.2, R6.2, R8.2, R9.2, R10.2, R11.2, R12.2, TR1.1, TR2.1, U1.2 (GND), U2.1, U3.1; also elsewhere on the board
LO_I: J2.13; also elsewhere on the board
LPF_ENABLE: K4.13; also elsewhere on the board
unnamed: C17.1, D5.1, R4.2, R5.1
unnamed: C20.1, D6.1, R12.1, R13.1
unnamed: D4.2, K4.16, Q3.1
unnamed: D5.2, R6.1, R9.1, TR2.4
unnamed: D6.2, R10.1, R11.1, TR1.2, TR2.3
unnamed: J3.1, J4.2, SW1.2 (B)
unnamed: J3.3, J4.1
REV_PWR: J2.5, R13.2
RF_ENVELOPE: J2.9; also elsewhere on the board
RF_OUT: J2.10, K4.4
SWR_IN: TR1.3, TR2.2; also elsewhere on the board
TX_ENABLE: J2.2, Q3.2, R3.1; also elsewhere on the board
VBATT: J2.1, R7.2, R8.1

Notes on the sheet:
TX RX Switching
Linear Regulator
SWR Bridge

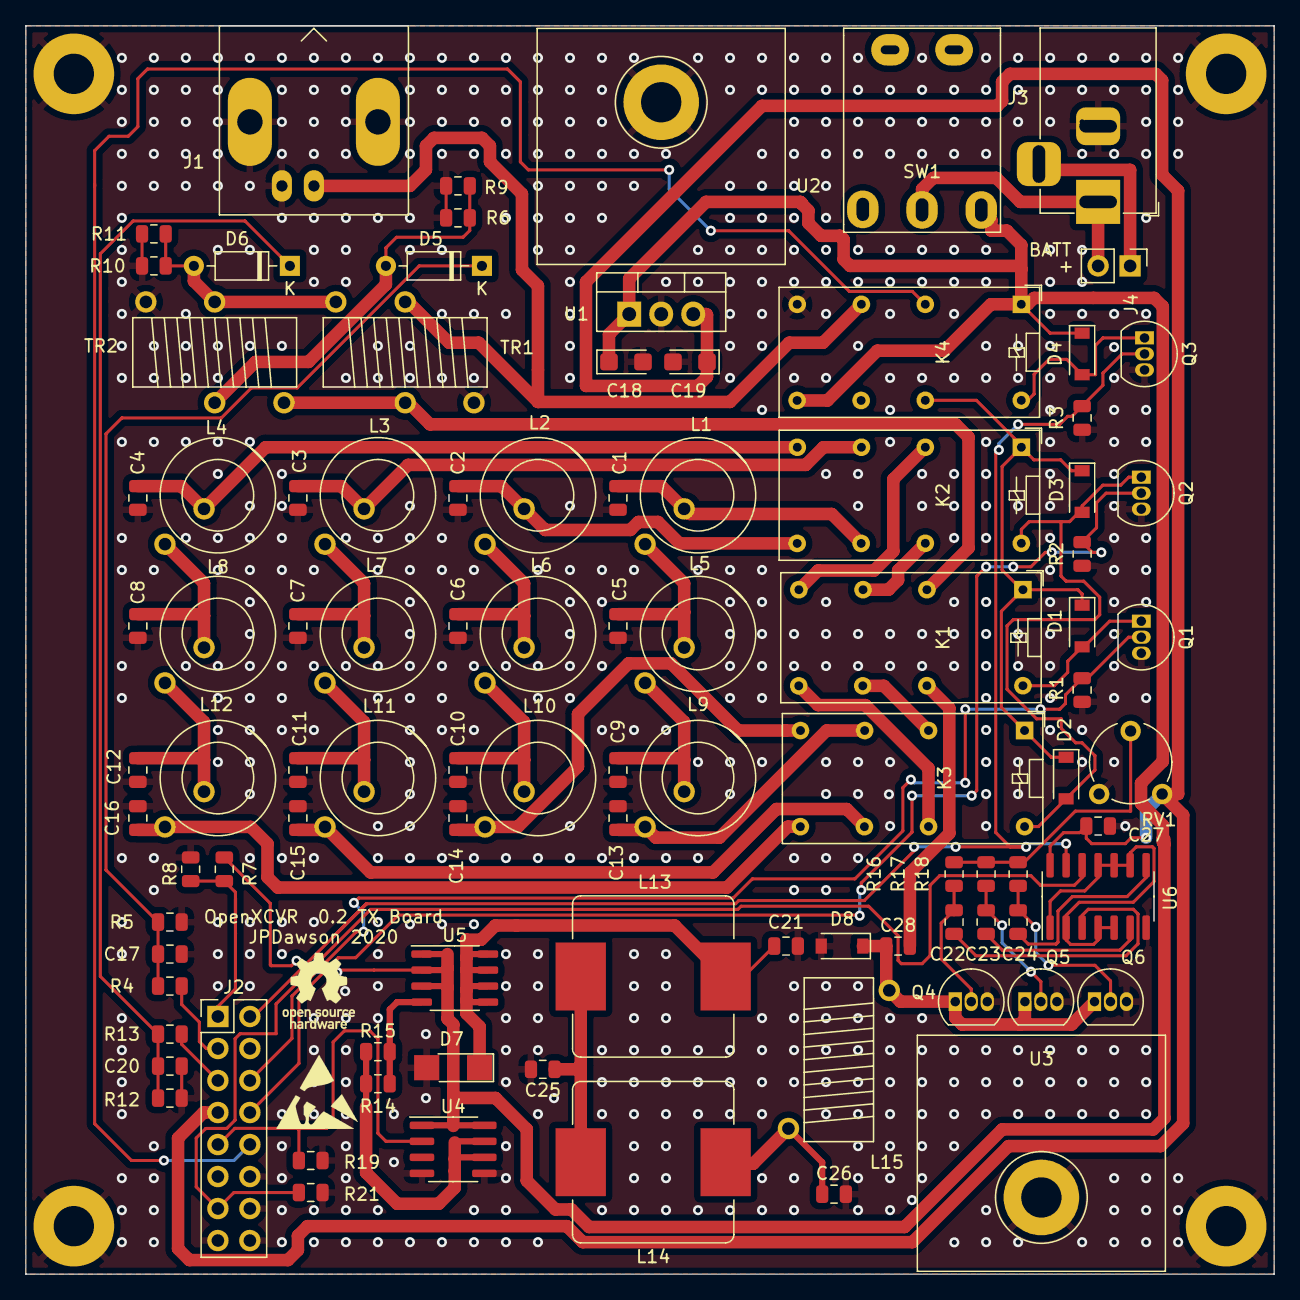
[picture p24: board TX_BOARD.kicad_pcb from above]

Board: 2 copper layers, 99.1 x 99.1 mm, 99 parts (0 on the bottom side), 59 nets.

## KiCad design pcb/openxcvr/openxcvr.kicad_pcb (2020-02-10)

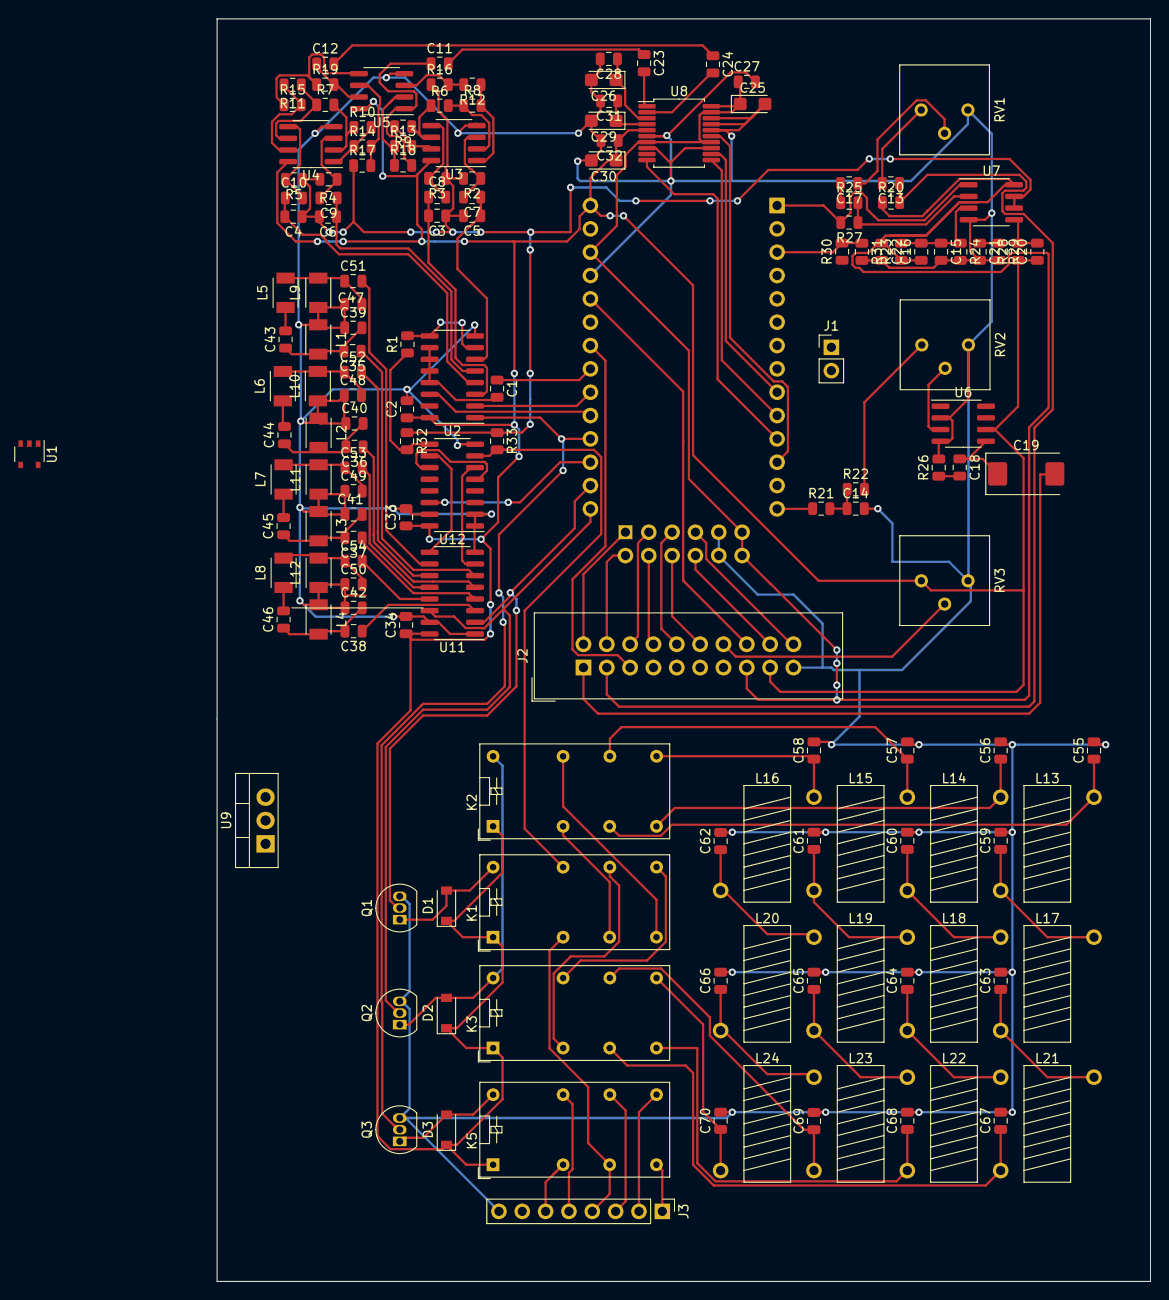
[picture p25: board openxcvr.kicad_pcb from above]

Board: 2 copper layers, 101.6 x 137.4 mm, 155 parts (1 on the bottom side), 129 nets.

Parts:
C1, C3, C4, C5, C6, C35, C36, C38, C51, C52, C53, C54: 100nF; C_0805_2012Metric
C2, C13, C15, C16, C17, C20, C21, C22, C27, C28, C31, C32, C33, C34: 100n; C_0805_2012Metric
C7, C8, C9, C10, C11, C12: 1uF; C_0805_2012Metric
C14, C18: 47nF; C_0805_2012Metric
C19: 100uF; CP_EIA-7343-31_Kemet-D
C23, C24: 1u; C_0805_2012Metric
C25, C26, C29, C30: 10u; CP_EIA-3216-18_Kemet-A
C37: 100nf; C_0805_2012Metric
C39, C45, C47, C61, C65: 390p; C_0805_2012Metric
C40, C48: 820p; C_0805_2012Metric
C41, C49: 1n6; C_0805_2012Metric
C42, C50: 3n; C_0805_2012Metric
C43: 100p; C_0805_2012Metric
C44: 200p; C_0805_2012Metric
C46: 1n; C_0805_2012Metric
C55, C67: 470p; C_0805_2012Metric
C56, C68: 270p; C_0805_2012Metric
C57, C69: 180p; C_0805_2012Metric
C58, C70: 56p; C_0805_2012Metric
C59, C63: 1.2n; C_0805_2012Metric
C60, C64: 680p; C_0805_2012Metric
C62, C66: 150p; C_0805_2012Metric
D1, D2, D3: 1N4148W; D_SOD-123
J1: BATTERY_CONNECTOR; PinHeader_1x02_P2.54mm_Vertical
J2: UI_CONNECTOR; IDC-Header_2x10_P2.54mm_Vertical
J3: Conn_01x08_Male; PinHeader_1x08_P2.54mm_Vertical
K1, K2, K3, K5: G5V-2; Relay_DPDT_Omron_G5V-2
L1, L9: 100n; L_TDK_NLV32_3.2x2.5mm
L2, L10: 220n; L_TDK_NLV32_3.2x2.5mm
L3, L5, L11: 470n; L_TDK_NLV32_3.2x2.5mm
L4, L6, L12: 1u; L_TDK_NLV32_3.2x2.5mm
L7: 2u2; L_TDK_NLV32_3.2x2.5mm
L8: 3u3; L_TDK_NLV32_3.2x2.5mm
L13, L21: 2.434u; FT37-INDUCTOR
L14, L22: 1.380u; FT37-INDUCTOR
L15, L23: 773n; FT37-INDUCTOR
L16, L24: 303n; FT37-INDUCTOR
L17: 3.012u; FT37-INDUCTOR
L18: 1.698u; FT37-INDUCTOR
L19: 904n; FT37-INDUCTOR
L20: 382n; FT37-INDUCTOR
Q1, Q2, Q3: BS170; TO-92_Inline
R1: 82R; R_0805_2012Metric
R2, R3, R4, R5, R20, R22, R32, R33: 10K; R_0805_2012Metric
R6, R7: 150R; R_0805_2012Metric
R8, R9, R10, R11, R12, R13, R14, R15, R16, R17, R18, R19: 2K2; R_0805_2012Metric
R21, R25, R31: 1K; R_0805_2012Metric
R23, R24, R28, R29: 100K; R_0805_2012Metric
R26: 10; R_0805_2012Metric
R27: 1M; R_0805_2012Metric
R30: 4K7; R_0805_2012Metric
RV1, RV2, RV3: 10K; Potentiometer_Bourns_3386P_Vertical
U1: 74LVC1G04; TSOP-5_1.65x3.05mm_P0.95mm
U2, U11, U12: SN74CBT3253; SOIC-16_3.9x9.9mm_P1.27mm
U3, U4, U5: LM4562; SOIC-8_3.9x4.9mm_P1.27mm
U6: LM386; SOIC-8_3.9x4.9mm_P1.27mm
U7: MCP6002-xSN; SOIC-8_3.9x4.9mm_P1.27mm
U8: PCM1802; SSOP-20_5.3x7.2mm_P0.65mm
U9: LM7805_TO220; TO-220-3_Vertical
U10: MAX_1000; max1000

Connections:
+2V5: C3.1, C4.1, C5.2, C6.2, R2.2, R3.1, R4.2, R5.1, R16.1, R17.1, R32.1, R33.1, U7.6, U7.7
+3V3: C16.1, C22.1, C25.1, C27.1, J2.15, R20.1, R23.1, U7.8, U8.7, U8.14, U8.19, U8.20, U10.26, U10.34, U10.40
+5V: C2.1, C20.1, C30.1, C32.1, C33.1, C34.1, D1.1, D2.1, D3.1, J2.17, K1.1, K2.1, K3.1, K5.1, R28.1, RV3.1, U1.5, U2.16, U3.8, U4.8, U5.8, U6.6, U8.5, U10.28, U11.16, U12.16
+12V: J1.1, R30.1, U9.1
ANTENNA: J3.6, K5.4
BAND_0: Q2.2, U10.15, U11.14
BAND_1: Q1.2, U10.16, U11.2
BAND_2: U10.17, U12.14
BANK_0_A: U11.7, U12.6
BANK_0_B: U11.9, U12.10
BATTERY: R30.2, R31.1, U10.3
BCK: U8.11, U10.10
BPF_2_4_A: C38.1, U11.3
BPF_2_4_B: C54.2, U11.13
BPF_4_8_A: C37.1, U11.4
BPF_4_8_B: C53.2, U11.12
BPF_8_16_A: C36.1, U11.5
BPF_8_16_B: C52.2, U11.11
BPF_16_30_A: C35.1, U11.6
BPF_16_30_B: C51.2, U11.10
DOUT: U8.12, U10.9
GND: C2.2, C14.2, C15.2, C21.2, C22.2, C25.2, C26.2, C27.2, C28.2, C29.2, C30.2, C31.2, C32.2, C33.2, C34.2, C39.1, C40.1, C41.1, C42.1, C47.1, C48.1, C49.1, C50.1, C55.2, C56.2, C57.2, C58.2, C59.2, C60.2, C61.2, C62.2, C63.2, C64.2, C65.2, C66.2, C67.2, C68.2, C69.2, C70.2, J1.2, J2.19, J3.8, L1.1, L2.1, L3.1, L4.1, L9.1, L10.1, L11.1, L12.1, Q1.3, Q2.3, Q3.3, R24.2, R26.2, R29.2, R31.2, RV1.3, RV2.3, RV3.3, U1.3, U2.8, U3.4, U4.4, U5.4, U6.2, U6.4, U7.4, U8.6, U8.8, U8.13, U8.16, U8.17, U8.18, U9.2, U10.25, U10.33, U10.39, U11.1, U11.8, U11.15, U12.1, U12.2, U12.8, U12.15
IR: J2.16, U10.24
I_NEG: C3.2, C8.1, U2.3
I_POS: C5.1, C7.1, U2.6
LCD4: J2.8, U10.36
LCD5: J2.6, U10.30
LCD6: J2.4, U10.35
LCD7: J2.2, U10.29
LCD_CONTRAST: J2.14, RV3.2
LCD_E: J2.12, U10.37
LCD_RS: J2.10, U10.31
LO_I: U2.14, U10.19
LO_Q: U2.2, U10.20
LPF_BAND_0_A: C55.1, K2.6, L13.1
LPF_BAND_0_B: C67.1, K3.6, L21.2
LPF_BAND_1_A: C56.1, K2.8, L14.1
LPF_BAND_1_B: C68.1, K3.8, L22.2
LPF_BAND_2_A: C57.1, K2.11, L15.1
LPF_BAND_2_B: C69.1, K3.11, L23.2
LPF_BAND_3_A: C58.1, K2.9, L16.1
LPF_BAND_3_B: C70.1, K3.9, L24.2
LRCK: U8.10, U10.11
MIC: R27.2, U7.1, U10.1
MIC_HDR: C13.1, J2.3, R20.2
unnamed: C1.2, U2.10, U2.11, U2.12, U2.13
unnamed: C7.2, R2.1, U3.3
unnamed: C8.2, R3.2, U3.5
unnamed: C9.2, R4.1, U4.3
unnamed: C10.2, R5.2, U4.5
unnamed: C11.1, R18.2, U5.1
unnamed: C12.1, R19.2, U5.7
unnamed: C13.2, RV1.1
unnamed: C14.1, R21.2, R22.1
unnamed: C15.1, C16.2, R23.2, R24.1, U7.3
unnamed: C17.1, RV1.2
unnamed: C17.2, R25.1
unnamed: C18.1, C19.1, U6.5
unnamed: C18.2, R26.1
unnamed: C20.2, C21.1, R28.2, R29.1, U7.5
unnamed: C23.2, U8.1
unnamed: C24.2, U8.2
unnamed: C26.1, C28.1, U8.3
unnamed: C29.1, C31.1, U8.4
unnamed: C35.2, C39.2, C43.1, L1.2
unnamed: C36.2, C40.2, C44.1, L2.2
unnamed: C37.2, C41.2, C45.1, L3.2
unnamed: C38.2, C42.2, C46.1, L4.2
unnamed: C43.2, L5.1
unnamed: C44.2, L6.1
unnamed: C45.2, L7.1
unnamed: C46.2, L8.1
unnamed: C47.2, C51.1, L5.2, L9.2
unnamed: C48.2, C52.1, L6.2, L10.2
unnamed: C49.2, C53.1, L7.2, L11.2
unnamed: C50.2, C54.1, L8.2, L12.2
unnamed: C59.1, L13.2, L17.1
unnamed: C60.1, L14.2, L18.1
unnamed: C61.1, L15.2, L19.1
unnamed: C62.1, L16.2, L20.1
unnamed: C63.1, L17.2, L21.1
unnamed: C64.1, L18.2, L22.1
unnamed: C65.1, L19.2, L23.1
unnamed: C66.1, L20.2, L24.1
unnamed: D1.2, K1.16, Q1.1
unnamed: D2.2, K2.16, K3.16, Q2.1
unnamed: D3.2, K5.16, Q3.1
unnamed: K1.6, K2.4
unnamed: K1.8, K2.13
unnamed: K1.9, K3.13
unnamed: K1.11, K3.4
unnamed: R1.2, U2.7, U2.9
unnamed: R6.1, R9.1, U3.6
unnamed: R6.2, R8.1, U3.2
unnamed: R7.2, R10.1, U4.2
unnamed: R10.2, R14.1, U4.1
unnamed: R7.1, R11.1, U4.6
unnamed: R11.2, R15.2, U4.7
unnamed: R8.2, R12.1, U3.1
unnamed: R12.2, R16.2, U5.3
unnamed: R13.1, R18.1, U5.2
unnamed: R9.2, R13.2, U3.7
unnamed: R14.2, R17.2, U5.6
unnamed: R15.1, R19.1, U5.5
unnamed: R22.2, RV2.1
unnamed: R25.2, R27.1, U7.2
unnamed: RV2.2, U6.3
unnamed: U1.4, U2.15
unnamed: U9.3, U10.27
unnamed: U12.5, U12.11
PA_IN: J3.1, K5.8
PA_OUT: J3.4, K1.4, K5.6
PB_0: J2.18, U10.38
PB_1: J2.20, U10.32
PTT: J2.5, U10.22
Q_NEG: C4.2, C10.1, U2.4
Q_POS: C6.1, C9.1, U2.5
RELAY_COMMON: J3.5, K5.13
RELAY_RX: J3.3, K5.11
RELAY_TX: J3.2, K5.9
RF_BPF: R1.1, R32.2, U12.9
RF_LPF: K1.13, R33.2, U12.7
RX_I: C11.2, C23.1
RX_Q: C12.2, C24.1
SCK: U8.15, U10.12
SPEAKER: R21.1, U10.14
SPEAKER_HDR: C19.2, J2.1
TRANSMIT_RF: C1.1, U10.21
TX_ENABLE: Q3.2, U1.2, U2.1, U10.18

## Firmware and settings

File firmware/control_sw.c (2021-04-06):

unsigned frequency_out = output("frequency_out");
unsigned control_out = output("control_out");
unsigned debug_out = output("debug_out");
unsigned debug_in = input("debug_in");
unsigned capture_in = input("capture_in");
unsigned power_in = input("power_in");
unsigned pps_count_in = input("pps_count_in");
unsigned adc_in = input("adc_in");
unsigned position_in = input("position_in");
unsigned push_button_in = input("pb_in");
unsigned i2c_in = input("i2c_in");
unsigned i2c_out = output("i2c_out");

#include <print.h>
#include <scan.h>
#include <stdio.h>

// int(round((2**32)*(2**32)/300e6))
#define FREQUENCY_STEP_MULTIPLIER 61489146912ul

// settings that get stored in eeprom
#define idx_frequency 0
#define idx_mode 1
#define idx_agc_speed 2
#define idx_step 3
#define idx_squelch 4
#define idx_volume 5
#define idx_max_frequency 6
#define idx_min_frequency 7
#define idx_mic_gain 8
#define idx_cw_speed 9
#define idx_pps_count 10

// settings that are transient
#define idx_band 11
#define idx_test_signal 12
#define idx_USB_audio 13
#define idx_tx 14
#define idx_mute 15

unsigned settings[16];

void apply_settings();
void update_lcd(unsigned cat_mode);

#include "i2c.h"
i2c bus;
#include "eeprom.h"
#include "load_store.h"
#include "ui.h"
#include "transmit.h"
#include "utils.h"

// convert a frequency in Hertz into a frequency in NCO step size.
unsigned convert_to_steps(unsigned x) {
  unsigned long long y = x * FREQUENCY_STEP_MULTIPLIER;
  y >>= 32;
  y *= 150000000;
  y = divide(y, settings[idx_pps_count]);
  return y;
}

// convert dBs to s-meter scale
int read_smeter() {

  unsigned power = to_dB(fgetc(power_in));

  // ADC has 1.5Vpk = 1.06Vrms = 0.0225W into 50ohm = 22.5mW = 13.5dBm
  // Receiver has a gain of (220/50)*(3300/100) = 145.2 = 43dB
  // so full scale pk magnitude = 13.5 - 43 = -29.5dBm at input connector

  int power_dbm = -29 - (102 - power);
  int s_scale;

  if (power_dbm < -63) {
    power_dbm += 127;
    s_scale = power_dbm / 6;
  } else {
    power_dbm += 73;
    s_scale = 9 + power_dbm / 10;
  }

  return s_scale;
}

const attenuation_settings[10] = {17, 8, 7, 6, 5, 4, 3, 2, 1, 0};

void apply_settings() {
  unsigned attenuation;
  unsigned control = 0;
  int rx_frequency_correction[6];

  // set volume
  attenuation = attenuation_settings[settings[idx_volume]];
  if (settings[idx_mute]) {
    attenuation = 18; // use a special value to indicate mute due to squelch
  }
  control |= (attenuation << 8);

  // set mode
  settings[idx_mode] &= 0x7;
  control |= settings[idx_mode];

  // set agc speed
  settings[idx_agc_speed] &= 0x3;
  control |= (settings[idx_agc_speed] << 4);

  if (settings[idx_test_signal])
    control |= 0x00000040u;
  if (settings[idx_USB_audio])
    control |= 0x00100000u;

  // force a band
  if (settings[idx_band] & 0x8) {
    control |= ((settings[idx_band] & 0x7) << 21);
  } else {
    if (settings[idx_frequency] >= 2000000 &&
        settings[idx_frequency] < 4000000) {
      control |= (3 << 21);
    } else if (settings[idx_frequency] >= 4000000 &&
               settings[idx_frequency] < 8000000) {
      control |= (2 << 21);
    } else if (settings[idx_frequency] >= 8000000 &&
               settings[idx_frequency] < 16000000) {
      control |= (1 << 21);
    } else if (settings[idx_frequency] >= 16000000 &&
               settings[idx_frequency] < 30000000) {
      control |= (0 << 21);
    } else {
      control |= (4 << 21);
    }
  }

  // set mic gain
  settings[idx_mic_gain] &= 0xf;
  control |= (settings[idx_mic_gain] << 24);
  // Mode Clock Divider   NCO Offset
  rx_frequency_correction[0] = -12207; // AM    2   48828    -12207
  rx_frequency_correction[1] = -24414; // NFM   1   97656    -24414
  rx_frequency_correction[2] = -24414; // FM    1   97656    -24414
  rx_frequency_correction[4] = -10681; // LSB   4   24414    -10681
  rx_frequency_correction[3] = -13732; // USB   4   24414    -13732
  rx_frequency_correction[5] = -8138;  // CW    3   32552    -8138

  if (tx_on && settings[idx_frequency] >= 3500000 &&
      settings[idx_frequency] <= 29700000)
    control |= 0x00000008u;
  if (tx_on) {
    // TX is direct conversion
    fputc(convert_to_steps(settings[idx_frequency]), frequency_out);
  } else {
    // Rx uses Fs/4 IF
    fputc(convert_to_steps(settings[idx_frequency] +
                           rx_frequency_correction[settings[idx_mode]]),
          frequency_out);
  }

  fputc(control, control_out);
}

void update_lcd(unsigned cat_mode) {
  // update display status
  LCD_CLEAR() //this takes a long time, so might need to reivew
  LCD_LINE1()
  lcd_print_decimal(settings[idx_frequency], 5, 3);
  if(cat_mode){
    lcd_print(" C ");
  } else {
    lcd_print("   ");
  }
  print_option(MODES, settings[idx_mode]);
  LCD_LINE2()
  print_option(SMETER, read_smeter());
}

void main() {

  stdout = debug_out;
  stdin = debug_in;
  puts("FPGA transceiver v 0.01\n");

  unsigned int power, i, pps_count;
  unsigned wake_time = 0;
  int audio;
  int position_change = 0;

  // initialise peripherals
  lcdInit();
  i2c_init(&bus, i2c_in, i2c_out);
  load_settings(&bus, 0); // page 0 contains power up settings
  apply_settings();
  update_lcd(cat_mode);

  while (1) {

    if(cat_mode && ready(stdin)){
      cat();
    }


    if(tx_on){

        if (timer_low() - wake_time > 500000) {
          wake_time = timer_low();
          transmit();
        }

    } else {

        if (timer_low() - wake_time > 5000000) {
          wake_time = timer_low();

          settings[idx_mute] = read_smeter() < settings[idx_squelch];

          // If knob is turned adjust frequency
          // don't store this in EEPROM to avoid wear
          position_change = get_position_change();
          if (position_change) {
            if (check_button(4)) {
              settings[idx_frequency] +=
                  position_change * step_sizes[settings[idx_step]] * 10;
            } else if (check_button(8)) {
              settings[idx_frequency] +=
                  position_change * step_sizes[settings[idx_step]] / 10;
            } else {
              settings[idx_frequency] +=
                  position_change * step_sizes[settings[idx_step]];
            }
            if (settings[idx_frequency] > settings[idx_max_frequency])
              settings[idx_frequency] = settings[idx_min_frequency];
            if ((int)settings[idx_frequency] < (int)settings[idx_min_frequency])
              settings[idx_frequency] = settings[idx_max_frequency];
            apply_settings();
          }

          //pressing any key cancels cat mode
          if(cat_mode){
            if(check_button(3)){
              get_button(3);
              cat_mode = 0;
              settings[idx_tx] = 0;
            }
          }
          // if the menu was entered, update settings and
          // store them in EEPROM
          else{
            if (do_ui()) {
              apply_settings();
              store_settings(&bus, 0);
            }
          }

          update_lcd(cat_mode);

          // check transmit button etc
          check_ptt();

      }
    }
  }
}

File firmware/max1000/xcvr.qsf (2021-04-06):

# -------------------------------------------------------------------------- #
#
# Copyright (C) 2019  Intel Corporation. All rights reserved.
# Your use of Intel Corporation's design tools, logic functions 
# and other software and tools, and any partner logic 
# functions, and any output files from any of the foregoing 
# (including device programming or simulation files), and any 
# associated documentation or information are expressly subject 
# to the terms and conditions of the Intel Program License 
# Subscription Agreement, the Intel Quartus Prime License Agreement,
# the Intel FPGA IP License Agreement, or other applicable license
# agreement, including, without limitation, that your use is for
# the sole purpose of programming logic devices manufactured by
# Intel and sold by Intel or its authorized distributors.  Please
# refer to the applicable agreement for further details, at
# https://fpgasoftware.intel.com/eula.
#
# -------------------------------------------------------------------------- #
#
# Quartus Prime
# Version 19.1.0 Build 670 09/22/2019 SJ Lite Edition
# Date created = 15:23:34  November 29, 2019
#
# -------------------------------------------------------------------------- #
#
# Notes:
#
# 1) The default values for assignments are stored in the file:
#		xcvr_assignment_defaults.qdf
#    If this file doesn't exist, see file:
#		assignment_defaults.qdf
#
# 2) Altera recommends that you do not modify this file. This
#    file is updated automatically by the Quartus Prime software
#    and any changes you make may be lost or overwritten.
#
# -------------------------------------------------------------------------- #


set_global_assignment -name FAMILY "MAX 10"
set_global_assignment -name DEVICE 10M08SAU169C8G
set_global_assignment -name TOP_LEVEL_ENTITY max1000
set_global_assignment -name ORIGINAL_QUARTUS_VERSION 19.1.0
set_global_assignment -name PROJECT_CREATION_TIME_DATE "15:23:34  NOVEMBER 29, 2019"
set_global_assignment -name LAST_QUARTUS_VERSION "19.1.0 Lite Edition"
set_global_assignment -name PROJECT_OUTPUT_DIRECTORY output_files
set_global_assignment -name MIN_CORE_JUNCTION_TEMP 0
set_global_assignment -name MAX_CORE_JUNCTION_TEMP 85
set_global_assignment -name ERROR_CHECK_FREQUENCY_DIVISOR 256
set_global_assignment -name POWER_PRESET_COOLING_SOLUTION "23 MM HEAT SINK WITH 200 LFPM AIRFLOW"
set_global_assignment -name POWER_BOARD_THERMAL_MODEL "NONE (CONSERVATIVE)"
set_global_assignment -name FLOW_ENABLE_POWER_ANALYZER ON
set_global_assignment -name POWER_DEFAULT_INPUT_IO_TOGGLE_RATE "12.5 %"
set_global_assignment -name PARTITION_NETLIST_TYPE SOURCE -section_id Top
set_global_assignment -name PARTITION_FITTER_PRESERVATION_LEVEL PLACEMENT_AND_ROUTING -section_id Top
set_global_assignment -name PARTITION_COLOR 16764057 -section_id Top
set_location_assignment PIN_H6 -to clk_in
set_location_assignment PIN_E6 -to reset_in
set_global_assignment -name VCCA_USER_VOLTAGE 3.3V
set_global_assignment -name NOMINAL_CORE_SUPPLY_VOLTAGE 3.0V
set_global_assignment -name ENABLE_OCT_DONE ON
set_global_assignment -name EXTERNAL_FLASH_FALLBACK_ADDRESS 00000000
set_global_assignment -name USE_CONFIGURATION_DEVICE OFF
set_global_assignment -name INTERNAL_FLASH_UPDATE_MODE "SINGLE IMAGE WITH ERAM"
set_global_assignment -name CRC_ERROR_OPEN_DRAIN OFF
set_global_assignment -name STRATIX_DEVICE_IO_STANDARD "3.3-V LVTTL"
set_global_assignment -name OUTPUT_IO_TIMING_NEAR_END_VMEAS "HALF VCCIO" -rise
set_global_assignment -name OUTPUT_IO_TIMING_NEAR_END_VMEAS "HALF VCCIO" -fall
set_global_assignment -name OUTPUT_IO_TIMING_FAR_END_VMEAS "HALF SIGNAL SWING" -rise
set_global_assignment -name OUTPUT_IO_TIMING_FAR_END_VMEAS "HALF SIGNAL SWING" -fall
set_location_assignment PIN_D8 -to leds[7]
set_location_assignment PIN_C10 -to leds[6]
set_location_assignment PIN_C9 -to leds[5]
set_location_assignment PIN_B10 -to leds[4]
set_location_assignment PIN_A10 -to leds[3]
set_location_assignment PIN_A11 -to leds[2]
set_location_assignment PIN_A9 -to leds[1]
set_location_assignment PIN_A8 -to leds[0]
set_global_assignment -name ENABLE_SIGNALTAP OFF
set_global_assignment -name USE_SIGNALTAP_FILE stp2.stp
set_location_assignment PIN_H13 -to lo_i
set_location_assignment PIN_G12 -to lo_q
set_location_assignment PIN_A4 -to rs232_rx
set_location_assignment PIN_B4 -to rs232_tx
set_location_assignment PIN_J2 -to speaker
set_location_assignment PIN_H4 -to sclk_out
set_location_assignment PIN_H5 -to lrclk_in
set_location_assignment PIN_K10 -to bclk_in
set_location_assignment PIN_H8 -to dout_in
set_location_assignment PIN_B5 -to rs232_cts
set_location_assignment PIN_A6 -to rs232_rtr
set_location_assignment PIN_J12 -to band[1]
set_location_assignment PIN_J13 -to band[2]
set_location_assignment PIN_L12 -to band[0]
set_location_assignment PIN_K11 -to tx_enable
set_location_assignment PIN_M3 -to lcd_data[3]
set_location_assignment PIN_N3 -to lcd_data[2]
set_location_assignment PIN_L3 -to lcd_data[1]
set_location_assignment PIN_N2 -to lcd_data[0]
set_location_assignment PIN_K2 -to lcd_e
set_location_assignment PIN_M2 -to lcd_rs
set_location_assignment PIN_M1 -to quad_a
set_location_assignment PIN_K1 -to quad_b
set_location_assignment PIN_J10 -to scl
set_location_assignment PIN_H10 -to sda
set_location_assignment PIN_B11 -to scl_pu
set_location_assignment PIN_G13 -to sda_pu
set_instance_assignment -name CURRENT_STRENGTH_NEW 4MA -to lcd_data[3]
set_instance_assignment -name CURRENT_STRENGTH_NEW 8MA -to dout_in
set_instance_assignment -name CURRENT_STRENGTH_NEW 4MA -to lcd_data[2]
set_instance_assignment -name CURRENT_STRENGTH_NEW 4MA -to lcd_data[1]
set_instance_assignment -name CURRENT_STRENGTH_NEW 4MA -to lcd_data[0]
set_instance_assignment -name CURRENT_STRENGTH_NEW 4MA -to lcd_data
set_instance_assignment -name CURRENT_STRENGTH_NEW 4MA -to lcd_e
set_instance_assignment -name CURRENT_STRENGTH_NEW 4MA -to lcd_rs
set_location_assignment PIN_K12 -to rf
set_location_assignment PIN_J1 -to pps
set_global_assignment -name VHDL_FILE ../serial_demux.vhd
set_global_assignment -name VHDL_FILE ../serial_mux.vhd
set_global_assignment -name VHDL_FILE ../i2c.vhd
set_global_assignment -name VERILOG_FILE ../rotary_encoder.v
set_global_assignment -name QIP_FILE adc/adc/synthesis/adc.qip
set_global_assignment -name VHDL_FILE ../fifo.vhd
set_global_assignment -name VHDL_FILE ../serial_out.vhd
set_global_assignment -name VHDL_FILE ../serial_in.vhd
set_global_assignment -name VERILOG_FILE ../main_0.v
set_global_assignment -name VERILOG_FILE ../transceiver.v
set_global_assignment -name VERILOG_FILE max1000.v
set_global_assignment -name QIP_FILE xcvr_pll.qip
set_global_assignment -name SDC_FILE timing_constraints.sdc
set_global_assignment -name SOURCE_FILE db/xcvr.cmp.rdb
set_global_assignment -name QIP_FILE io.qip
set_global_assignment -name SIP_FILE io.sip
set_global_assignment -name QIP_FILE output_buffer.qip
set_global_assignment -name SIP_FILE output_buffer.sip
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

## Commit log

2019-11-23 integrate filter and agc into receiver
2020-01-04 Experiment getting receiver working with built in ADC
2020-01-06 fix error in downconverter
    [control_sw.c]
2020-01-09 Increase ADC bits to 24, increase DSP path from 16 to 18 bits
2020-01-10 Add gain and power outputs to control software
2020-01-11 Improve AGC by adding attack, decay and hang timings. Add soft and hard clipping to Audio output to remove clicks. Make ADC gain software controlled. Add fast magnitude measurement. Calculate s-scale
2020-01-12 Switch cleanly between tx and RX
2020-01-13 Add GPS 1pps counter, rescale volume from 0 to 9, use slow barrel shifter in audio agc, reduce mic sample rate to 100KHz
2020-01-13 Update filter coeeficients
2020-01-14 Add ability to read extra ADC channels from software
2020-02-10 Add PCB designs
    [BOM.ods, LPF.sch, MAX1000.sch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]
2020-02-15 Candidate design
    [LPF.sch, MAX1000.sch, RADIO.kicad_pcb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]
2020-02-15 Add gerbers
    [RADIO-B_Cu.gbl, RADIO-B_Mask.gbs, RADIO-B_Paste.gbp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]
2020-02-21 Update filter measurements
2020-03-24 Get things working with rev 1 PCB
    [MAX1000.sch, RADIO.dsn, RADIO.kicad_pcb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]
2020-04-16 reduce AF sample rate to 50KHz
2020-04-20 convert to symetrical filters
2020-05-01 Add eeprom load store capability
    [MAX1000.sch, RADIO.kicad_pcb, RADIO.sch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]
2020-06-11 update rev0.2 PCB
    [LPF.sch, MAX1000.sch, RADIO.kicad_pcb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]
2020-06-13 Review and update schematic
    [LPF.sch, MAX1000.sch, RADIO.kicad_pcb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]
2020-06-15 Review schematic and PCB layout
    [BOM.ods, Block Diagram.kicad_pcb, Block Diagram.sch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]
2020-06-17 PCB reviewed and updated
    [Block Diagram.kicad_pcb, Block Diagram.sch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]
2020-06-18 move resistors near LCD mounting hole
    [RADIO-B_Cu.gbl, RADIO-B_Mask.gbs, RADIO-B_Paste.gbp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]
2020-07-14 Add power/SWR and battery meter
2020-07-18 Basic SSB working, but running short of memory
    [control_sw.c]
2020-07-20 other minor tidy up, some not working
    [control_sw.c, ui.h]
2020-07-20 Fix some errors introduced in tidy up, add CW speed menu item
    [control_sw.c, load_store.h, ui.h]
2020-08-04 Add gps calibration menu option
2021-02-25 correct divide ratio comment
    [control_sw.c]
2021-03-28 use a higher sampling rate for SSB to avoid noise near DC
    [control_sw.c]
2021-03-28 Correct bandwidth of audio filter to match 50kHz sample rate
